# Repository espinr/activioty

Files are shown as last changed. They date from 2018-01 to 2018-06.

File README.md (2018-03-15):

# Activ-IoTy Timekeeping

> A scalable open platform for sports timekeeping based on standard IoT technologies

Activ-IoTy is a project, part of the **[Eclipse Open IoT Challenge 4.0](https://iot.eclipse.org/open-iot-challenge/)** aiming at enhancing sports timekeeping systems accurately, through IoT low-cost devices. ActivIoTy Timekeeping is an open set of tools for racing competitions (i.e., running, cycling, skating, and others) that provides easy-to-use tools for efficient timekeeping adapted to the nature of each race. ActivIoTy Timekeeping’s design is centered on rapid prototyping, open source, and standards. 

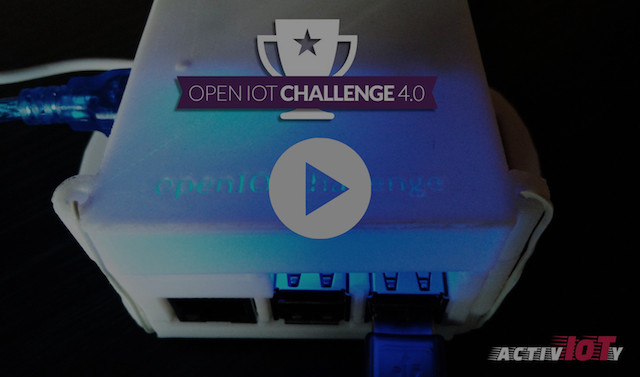
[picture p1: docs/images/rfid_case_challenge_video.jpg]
IoT Challenge 4.0 (https://youtu.be/2j3yzmwb5g8)


Read the [final report](./docs/) or [watch the video](https://youtu.be/2j3yzmwb5g8).

## Activ-IoTy at a glance

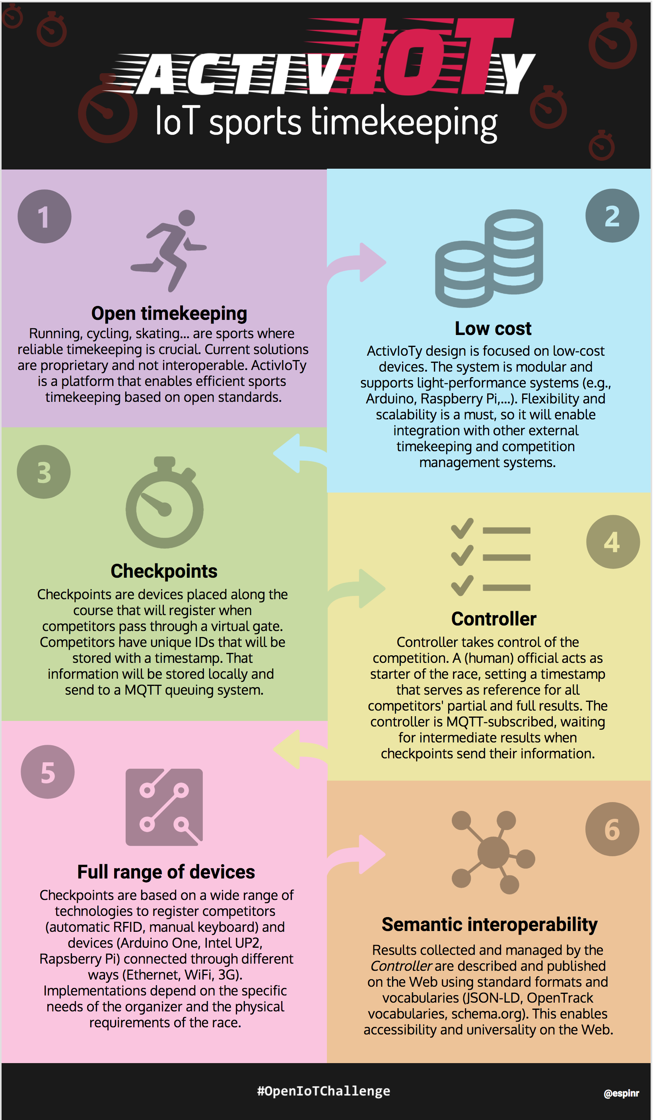
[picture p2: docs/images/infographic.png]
Activ-IoTy Infographic


* **Open timekeeping**: Running, cycling, skating… are sports where reliable timekeeping is crucial. Current solutions are proprietary and not interoperable. ActivIoTy Timekeeping is a platform that enables efficient sports timekeeping based on open standards.

   [Protocols and foundations of Activ-IoTy](./docs/protocols.md)
  
* **Low cost**: ActivIoTy Timekeeping design is focused on low-cost devices. The system is modular and supports light-performance systems (e.g., Arduino, Raspberry Pi,…). Flexibility and scalability is a must, so it will enable integration with other external timekeeping and competition management systems.
* ***Checkpoints***: Checkpoints are devices placed along the course that will register when competitors pass through a virtual gate. Competitors have unique IDs that will be stored with a timestamp. That information will be stored locally and  send to a MQTT queuing system.

   [MQTT and Workflow of Activ-IoTy](./docs/pubsub.md)
   
   [Checkpoint 1: RFID Reader + Raspberry Pi + Python](./docs/checkpoints/rfid-reader-python/)
   
   [Checkpoint 2: Bluetooth Keypad + Raspberry Pi + Python](./docs/checkpoints/bluetooth-keypad-python/)
   
   [Checkpoint 3: IR Remote + Arduino Uno](./docs/checkpoints/ir-arduino/)
   
   [Pseudo-checkpoint: Fona 3G + Arduino Lilypad](./docs/tracking/)

* ***Controller***: Controller takes control of the competition. A (human) official acts as starter of the race, setting a timestamp that serves as reference for all competitors' partial and full results. The controller is MQTT-subscribed, waiting for intermediate results when checkpoints send their information. 

   [MQTT and Workflow of Activ-IoTy](./docs/pubsub.md)
   
   [Controller](./docs/controller/)

* **Full range of devices**: *Checkpoints* are based on a wide range of technologies to register competitors (automatic RFID, manual keyboard) and devices (Arduino One, Intel UP2, Rapsberry Pi) connected through different ways (Ethernet, WiFi, 3G). Implementations depend on the specific needs of the organizer and the physical requirements of the race. 

* **Semantic interoperability**: Results collected and managed by the Controller are described and published on the Web using standard formats and vocabularies ([JSON-LD](https://json-ld.org/), [OpenTrack vocabularies](https://github.com/w3c/opentrack-cg), [schema.org](http://schema.org)). This enables accessibility and universality on the Web. 

   [Sample of results](./docs/controller/sample_results.jsonld) generated by the platform.

Check more information about the [components of Activ-IoTy](./docs/components.md)

[mainlogo]: ./docs/images/logo/activIoTy.svg "Logo of ActivIoTy Timekeeping"
[infographic]: ./docs/images/infographic.png "Components of ActivIoTy Timekeeping"

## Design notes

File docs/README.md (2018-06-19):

# Activ-IoTy Timekeeping Report

IoT Challenge 4.0 (https://youtu.be/2j3yzmwb5g8)

Watch [the video](https://youtu.be/2j3yzmwb5g8) summarizing all the work done in this project in just 3 minutes.

## 1. Description of the project

Athletics is perhaps the most popular sport in the world. It’s not only the most followed discipline during the Olympic Games, but Jogging is also extended in all countries as a base sport for kids or adult people. Fun races are also becoming popular, even among those who don’t do sports regularly. This trend is affecting positively to health and good habits of people.

More than 30 thousand running events take place in the U.S. every year, including 5k, 10k and 8K/5 mile races as well as half-marathons and marathons ([source](https://www.statista.com/topics/1743/running-and-jogging/)). It [is estimated](https://www.statista.com/statistics/190303/running-participants-in-the-us-since-2006/) that there are over 47 million of runners (doing running/jogging or trail running) in the U.S.

In EU28, figures show that running is part of the way of life of many people. For instance, the 31% of the Danish population are runners, 25% in Germany ([source](https://www.palgrave.com/gp/book/9781137446367)). Most of these runners take part in competitions. 

To make competitive running attractive among athletes, there are two important aspects to take into account: **accurate/official timekeeping**, and **publication of comparable results** for statistics and competition. We can achieve this with the complex and reliable systems of the competition organizers but this implies high costs. Also, these timing systems are not available in some developing countries.

Just as an example, in the following image of the Kenyan Cross Country Championships this year. There you can see how the *fastest* athletes in the world are selected to run in the World Championships, for instance. It shows an ordered queue of athletes, just after crossing the finish line. Two officials take notes on cardboard tables. These lists of results are published but, they won't be interoperable at all.

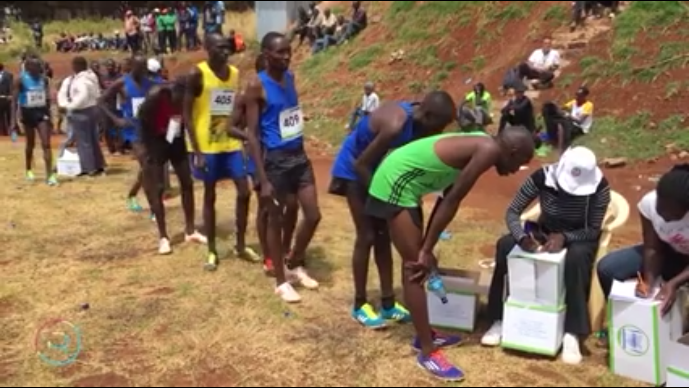
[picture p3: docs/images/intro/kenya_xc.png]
National Cross Country Championship in Kenya

Winners of the Kenyan Cross Country Championship 2018

### The solution

Activ-IoTy Timekeeping is a system that the concepts of rapid prototyping and Internet of Things to develop a modular low-cost solution for timekeeping and competition management. This system is based on standard technologies that enable **plug and play different devices** and share information with external servers to process the results, records, etc.

The following diagram shows the main components of Activ-IoTy: **Checkpoints** and **Controller(s)**.

1. *Checkpoints* registers both competitor's ID and timestamp. These components are the MQTT *publishers*.
2. *Controller*(s) collects the information sent by the *Checkpoints* and processes the information. So, these are the MQTT *subscribers*.
3. Other third-party *subscribers* may perform other activities (i.e., visualizations, integration with third-party services, etc.)  

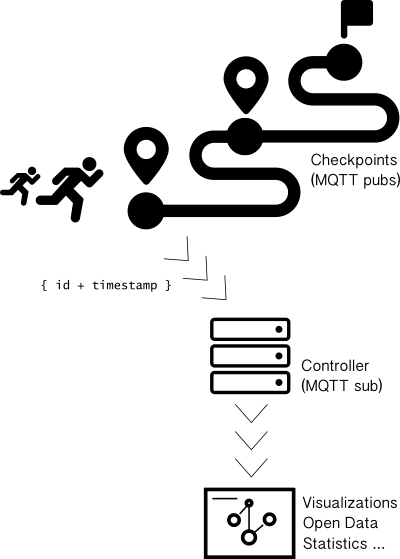
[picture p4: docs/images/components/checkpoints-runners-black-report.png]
Components of Activ-IoTy


### 1.1. *Checkpoints* 

Those components perform the timekeeping activities. They are 'virtual gates' where competitors check-in to complete the full itinerary of the race. The objective of a *checkpoint* is to inform the system which competitor arrives at that specific location, *timestamping* that check-in. Checkpoints are multimodal and fully configurable. They can be designed and implemented with different IoT components to satisfy the requirements of the race and the organizers.

This pilot includes several *checkpoints* with different devices, platforms, and configurations. This serves to test a wide range of racing scenarios.

#### 1.1.1. Checkpoint 1: RFID Reader + Raspberry Pi + Python

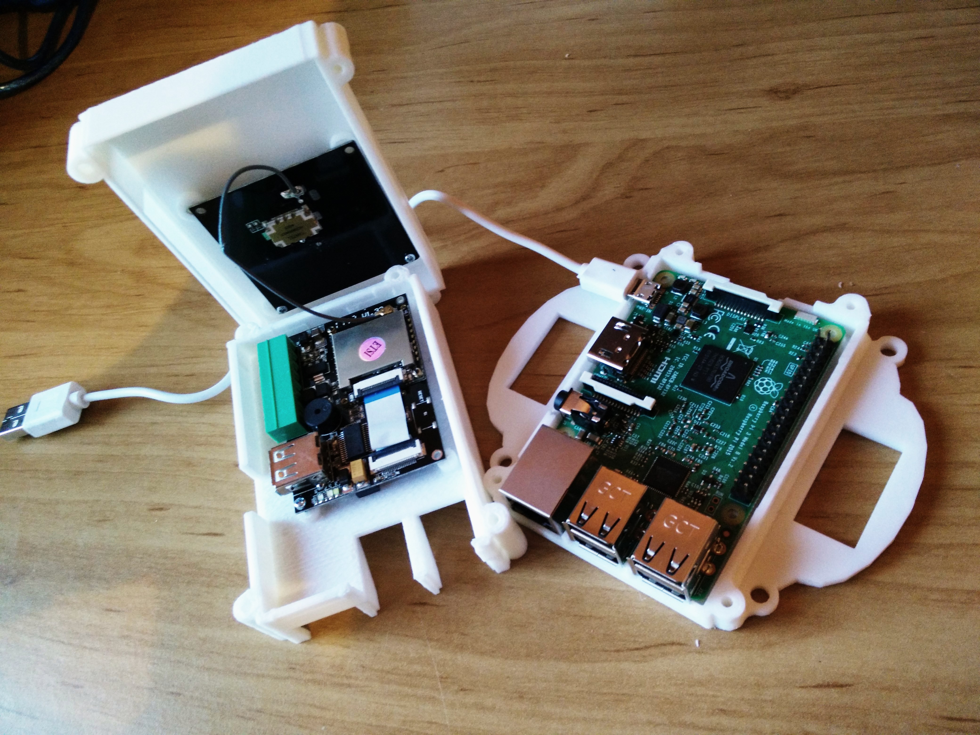
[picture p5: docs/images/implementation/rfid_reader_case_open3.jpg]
Checkpoint 1


This *Checkpoint* is based on a **IND903 UHF RFID Reader**, connected to a **Raspberry Pi** (or a **Intel Up Squared**). The reader controller, as well as the checkpoint are coded in Python. The MQTT Client is implemented using the **Paho** Python module.  

It is important to understand that each competitor taking part in a competition is identified by two unique IDs: 

1. the bib number: alphanumeric string that follows the organizers standards (it could be an alias, surname or bib number). In this case, an unsigned integer; and

2. an EPC (Electronic Product Code) corresponding to the RFID tag attached to their bib number. This tag follows the EPC C1G2 (Class 1 Generation 2) standard.

Check all the details and code in [Github page of this component](./checkpoints/rfid-reader-python).

The cost magnitude of this checkpoint depends on the antenna. The cost of the implementation of this pilot was around $150 (including RFID reader, sample tags, (5-6m reading range) antenna plus Rasberry Pi).

#### 1.1.2. Checkpoint 2: Bluetooth Keypad + Raspberry Pi + Python

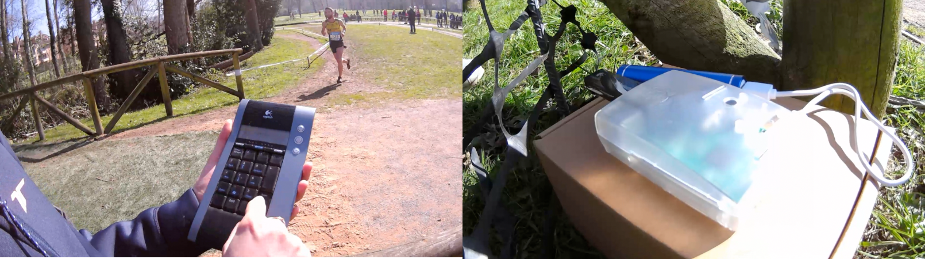
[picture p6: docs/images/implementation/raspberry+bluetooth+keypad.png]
Checkpoint 2


This is a cheap option of checkpoint implementation. 

Athletics events are usually controlled by officials with different roles such as: judges, timekeepers and starters. Other competitions must rely on officials with other roles, even volunteers or marshals. This checkpoint enables officials and volunteers to register athletes at checkpoints using a simple physical keypad to type athlete's bib numbers. 

Since all athletes must wear a visible bib identifier, this implementation is compatible with the existing rules of official competitions. Keypad may be substituted by a complete keyboard. Of course, the keypad could be a capacitive screen (i.e., tablet, smartphone, etc.) but it is probed that data input operators are more efficient with physical typing devices. Also they may be robust, even waterproof. 

Check all the details and code in [Github page of this component](./checkpoints/bluetooth-keypad-python).

The cost of this checkpoint is below $50.

#### 1.1.3. Checkpoint 3: IR Remote + Arduino Uno

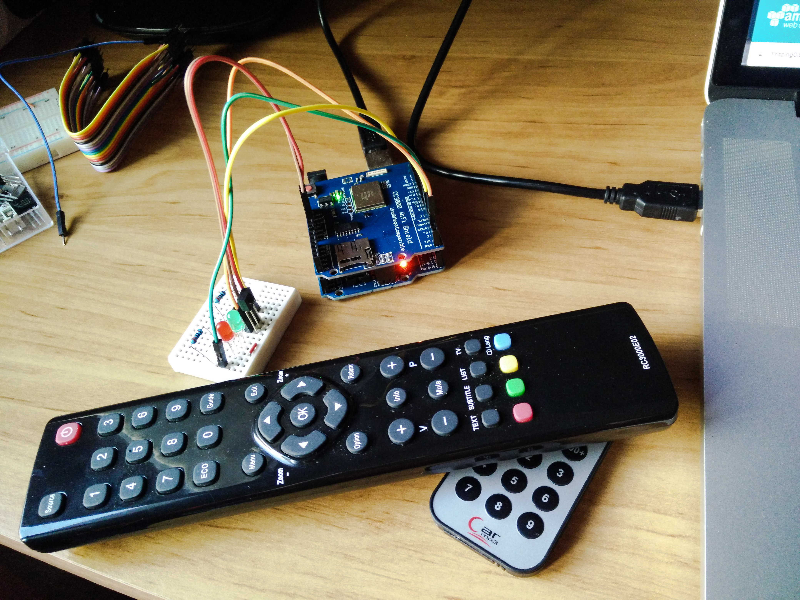
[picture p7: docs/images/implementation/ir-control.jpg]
IR Remote Control Checkpoint


Having in mind a less optimistic scenario –low budget, few resources–, I've implemented another checkpoint using a different solution. This option would cost less than $50 and it's really easy to use. It can be developed with a components from a basic Arduino-like kit. 

A system based on Infrared (IR) remote control, is not very reliable for our purpose since there must be a direct visual line between transmitter and receiver –likely TV remote controls. **More than a real solution, this is a proof of concept**.

Check all the details and code in [Github page of this component](./checkpoints/ir-arduino).

#### 1.1.4. MQTT publication

*Checkpoints* send an MQTT message once an athlete arrives. It is of the `{checkpoint-ID}/checkpoint` topic:

```
{
    "checkpoint" : { 
        "id" : "…",             // Required
        "geo" : { "lat" : "…", "lng" : "…" }    // Optional
    },
    "bibId" : "…",              // Either 'bib' or 'epc' are required
    "epc"   : "…",
    "timestamp"  : 0000000,     // (NTP) UNIX time Required
}
```

For check-in messages, it is required the checkpoint identifier (some information may be added, such as coordinates in case the checkpoint is on the move), the unique identifier of the competitor (we can have several, such as bib number and RFID tag), and the timestamp of the check-in. 

Check more information about the [PubSub design in the project](./pubsub.md).

#### 1.1.5. Scalability and further options

Trying to expand the features and ecosystem of the platform, a mobile checkpoint was created with a Fona 3G module and an Arduino Lilypad.

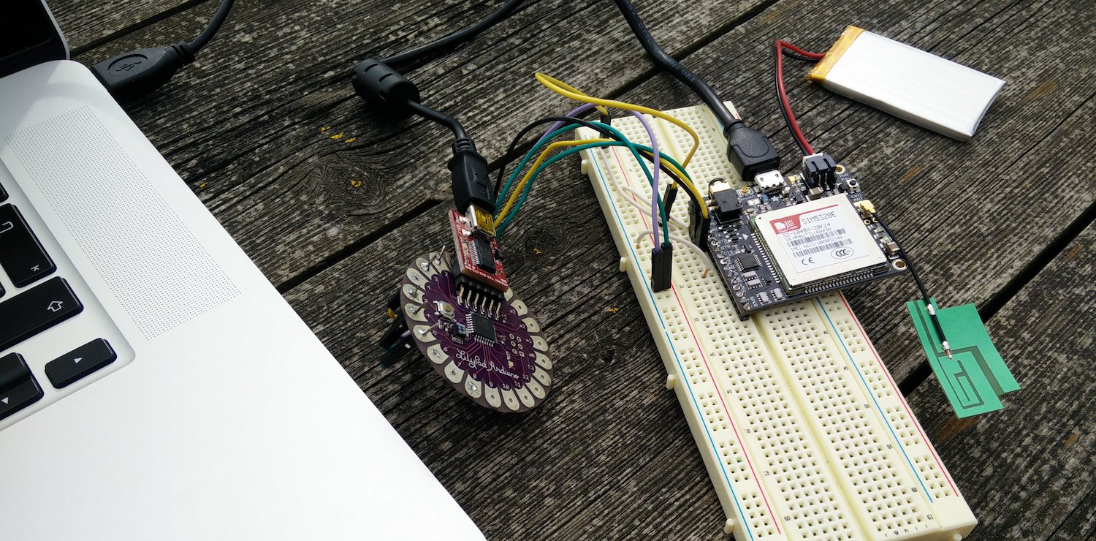
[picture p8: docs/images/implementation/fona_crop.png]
Pseudo-checkpoint


Check [more information about this checkpoint on the move](./tracking).

### 1.2. Controller(s)

A *Controller* is basically a **responsive Web application** that enables competition management, including the processing of *check-ins* performed on checkpoints along the race course. There may be several controllers for different purposes, implementing different features. The controller of this pilot enables a complete management of the competition, from the registration and management of athletes, checkpoints, race, start list and visualizing the competition in real time.

Activ-IoTy Controller screenshot (http://www.youtube.com/watch?v=nTlSV7WbGoE)
Check the [full video of a real example (at high speed) on YouTube](http://www.youtube.com/watch?v=nTlSV7WbGoE).

Read more information [about the *Controller*](./controller) and its implementation. In case you **want to [test it](http://activioty.ddns.net)**, drop me an email and I'll send you the *admin* credentials. You could sign up the app, but with the role of *athlete*, so you won't be able to create and manage races (only *admin*s can do it).

Some other components such as the **MQTT Broker** are described in [a more detailed document about components](./components.md) of the project.

> The strongest point of Activ-Ioty Timekeeping is scalability thanks to its design based on device independence and open standards.

The strongest point of Activ-Ioty Timekeeping is device independence so any kind of devices may be used to implement *checkpoints*. Likely *checkpoints*, *controllers* may be designed to manage the information to cover any competition requirement (e.g., relay races, multi-lap courses, time-trial races, and others). 

## 1.3. Technology and Standards

The cornerstone of Activ-IoTy Timekeeping is the implementation based on open standards. Since the platform is designed to allow different and heterogeneous devices and implementations, standard technologies are crucial for scalability, enhancement of the system, and also to preserve the integrity of data. 

Design and implementation were focused on the use of standard technologies, open source libraries and mounted on open hardware devices. **Python v3** and **Embed C++** are the selected programming languages for the devices (*Checkpoints*); **JavaScript**, for the *Controller*.

Stack of technologies and protocols of Activ-IoTy

Obviously, everything will run on the Internet. There are various underlying protocols since Activ-IoTy Timekeeping aims to be flexible in terms of physical connectivity. *Controllers* and *Checkpoints* may be installed in locations with strong WiFi signal (city or, town center), even with access to wired Ethernet routers, but also in the middle of the forest where we would need establish cellular GSM or 3G connections. Thus, the physical layer includes: [**IEEE 802.3 (Ethernet)**](http://www.ieee802.org/3/), [**IEEE 802.11 (WiFi)**](http://www.ieee802.org/11/) and [**WCDMA/HSDPA (3G)**](https://www.gsma.com/aboutus/gsm-technology/3gwcdma) protocols. 

In this sense, most of the tests were performed on WiFi access points, but the [Mobile Checkpoint](./tracking/) used a 3G cellular connection.

On top of the Internet, the transport layer is composed mainly by [**TCP** or Transmission Control Protocol](https://en.wikipedia.org/wiki/Transmission_Control_Protocol). [**UDP** or User Datagram Protocol](https://en.wikipedia.org/wiki/User_Datagram_Protocol) is used for specific applications such as time synchronization through external [NTP (Network Time Protocol)](http://www.ntp.org/ntpfaq/NTP-s-def.htm) servers.

### 1.3.1. MQTT, key in communications

*Checkpoints*, *controllers* and the rest of the modules are based on the Pub/Sub (Publication/Subscription) paradigm. Since the distributed system needs reliability and there is a potential lack of quality of communications, the solution uses [MQTT (Message Queuing Telemetry Transport)](http://mqtt.org/) as messaging protocol. MQTT allows *Checkpoints* (publishers) to send messages to the *Controllers* (subscribers). A *broker*, up and running in a reliable environment, will be in charge of delivering those messages effectively. 

**MQTT** implements different levels of Quality of service (QoS). **Integrity of data and rapidity is key for Activ-IoTy**. Also intermediate *Checkpoints* may be weak in terms of connectivity. Thus the system will implement **QoS 1 (at least once)**. Using QoS level 1, it is guaranteed that a message will be delivered at least once to the receiver. Messages can be delivered more than once but this will be taken into account and solved by the *Controller*.

The MQTT broker is implemented and running on a reliable UP-Squared accessible through the port 1883 of activioty.ddns.net. Regarding security, this broker does not provide a secure channel. This is a clear breach in the system but was done on purpose to offer real-time demonstrations in this prototype (i.e. jury of the challenge could subscribe to the MQTT queue in order to check the real messages running on the system, [like in the example](http://www.youtube.com/watch?v=nTlSV7WbGoE)). In case of real operation, the broker would implement either user authentication and SSL-secured transmissions.

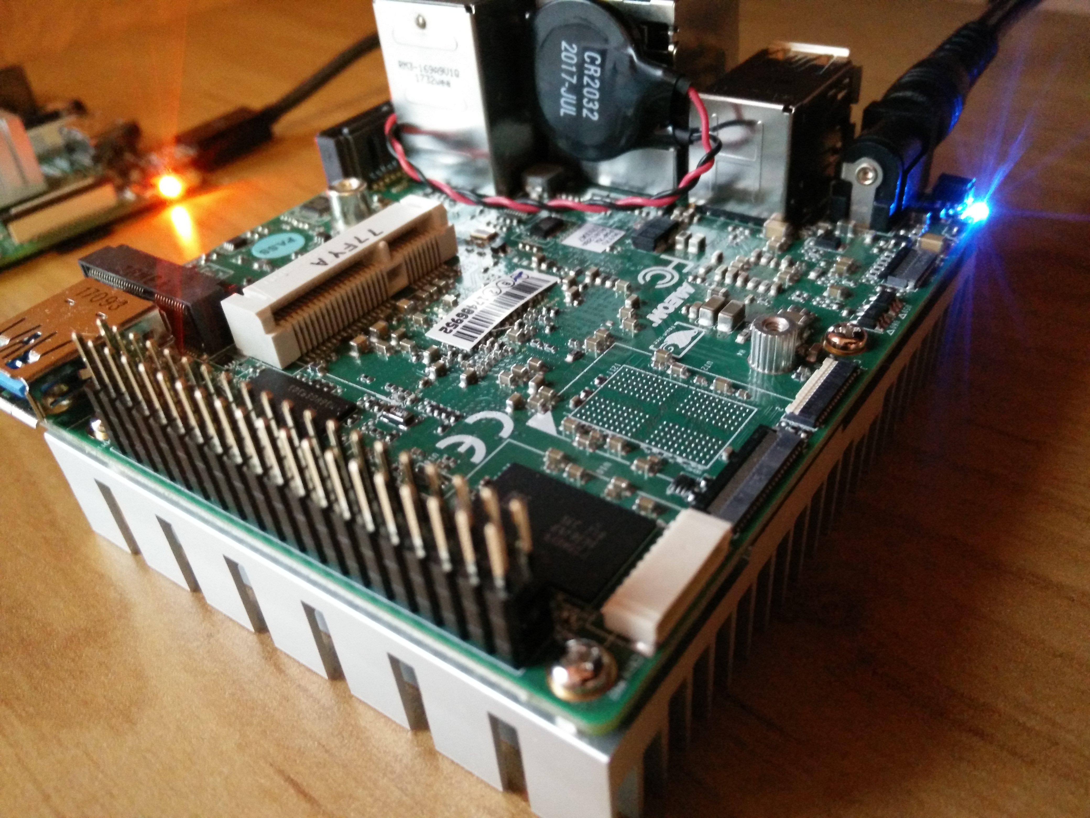
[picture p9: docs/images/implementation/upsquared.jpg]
Intel UpSquared

*UpSquared Board used for prototyping and where servers are running* 

### 1.3.2. Web Standards

The system implements some examples of visualizations and operation on the system. The *Controller* manages a MongoDB where stores all the information produced by the system, including the MQTT messages about competitors' *check-ins* at *checkpoints*. Additional Web services may be exposed on top of that database, giving access to third parties to build additional services or products. Just as an example of this, the system may offer **[HTTP (Hypertext Transfer Protocol)](https://www.w3.org/Protocols/) RESTful services** to get race results. Value of data is clear, so this may increase the usefulness of the platform, enabling innovation in further developments (e.g., integration with social networks, better visualizations, etc.). 

The final design was complemented by other specific top level standards that guarantee **interoperability among similar systems around the world**. The description of underlying entities of the database using the [**OpenTrack vocabularies**](https://w3c.github.io/opentrack-cg/), an initiative to model the domain of Athletics in a standard way. Through this **[Schema.org](http://schema.org)** based vocabulary (and taxonomies), the system describes athletes, clubs, competitions and results in a semantic way. Check the [results generated after the test](./controller/sample_results.jsonld) in **JSON-LD** format.

## 2. Applicability to industry

As mentioned before, the running/jogging market is growing every year and competitions happen everywhere at any time. There are many applications and products that probe the importance of competitiveness in this sport. For instance, most of the sports tracking mobile apps (Strava, Nike+, Endomondo, etc.) include gamification based on performances and rankings. So, Activ-IoTy is part of this trend. 

It is important to say that **reliable timekeeping systems already exist**. Indeed, this is problem solved since years ago. We are used to seeing real-time results while we watch Athletics at the Olympic Games on TV. In this case, a few big companies provide timing services to Athletics Federations to cover these competitions. Those costs are not affordable for the majority of race organizers. Another problem is the lack of open standards in those solutions, so most of them are proprietary and closed.

> Activ-IoTy Timekeeping brings innovation, new business opportunities and social benefits

Because of this, Activ-IoTy takes advantage of this *running bubble*, enabling an open platform to enrich sports. As part of the *open* concept (i.e., open source, open hardware, open data, open standards), **Activ-IoTy enables SMEs to develop new business opportunities, offering timekeeping services, including new devices and mechanisms, enhancing the final products, fostering innovation**. 

As shown in the tests, this pilot is fully functional, but not very robust –only basic features covered, and lack of testing in depth. It could become a robust platform where build services on top of it (i.e., consultancy services, specific applications, new check-in methods, integration with third-party services, etc.). Apart from the platform, there is a clear value of the data produced. Information managed by Activ-IoT could be also part of the [open data](https://en.wikipedia.org/wiki/Open_data) ecosystem, so this brings innovation, new business opportunities, and benefits for the community.

As a next step, apart from evolving the hardware of the platform, the *controller* should implement APIs to communicate with the current commercial sports systems. Integration with other platforms is key to a quick success of the platform.  

## 3. Lessons learned

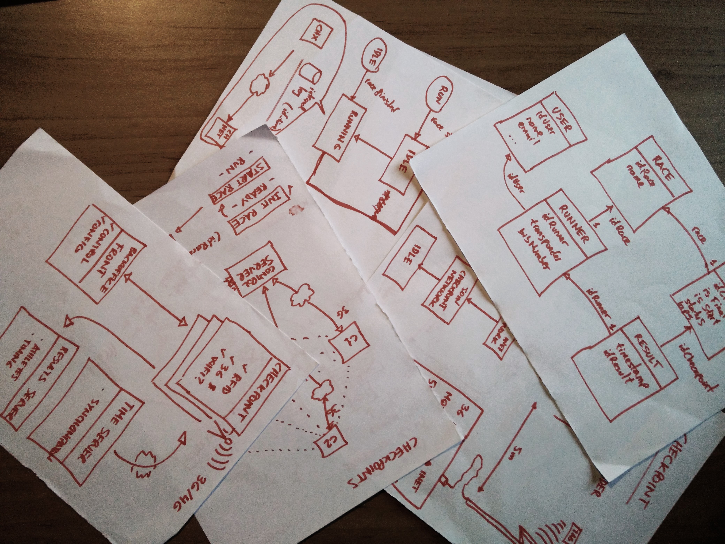
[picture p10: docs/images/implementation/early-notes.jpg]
Early notes


1. From software development to hardware prototyping. Back in December, I oriented the design phase as a software project –I have some experience in this field. When I started prototyping the checkpoints I found many issues that drove me crazy. I expected some parts to be easier, from the basic configuration of a device (e.g., installing the right BIOS, operating system, and drivers for the Intel UpSquared took me a few hours before it worked perfectly), to understanding why some implementations didn't work as expected (e.g., feeding the RFID reader with lower amperage than recommended). So, for this kind of projects, one **have to take into account more variables than a simple project of software development**.

2. *Community is key to the growth of IoT*. Developing new IoT solutions is a piece of cake. The Web is full of IoT enthusiasts aiming to help. I faced many issues during the implementation phase that were solved in minutes thanks to forums and blog posts on the Web. So, give attribution and share as well!! Eating my own dog food, code and documentation are available in the [Activ-IoTy Github Repository](https://github.com/espinr/activioty).  

3. Debugging is so hard… Most of the developments I've made for this project were based on existing libraries. Almost all worked properly at the first try, but not all. In case of low-level programming languages, such as some Arduino sketches, debugging was difficult in some parts. The lesson here is… be patient:-) 

4. **Python for arrays and bytes management**. Other software I used, such as the RDID-reader code, was created from scratch. Although I had no experience with it, I chose Python for its expected support of arrays and hexadecimal bytes required for the low-level communications protocol. It was a good experience. It's an intuitive programming language, with infinite modules to solve any challenge you face. The code may be run on some of the devices I had for the pilot (i.e., UpSquared and Raspberry Pi). 

5. **Beauty !== functional**. I bought an RFID Reader that has [worked right from the first try](https://www.youtube.com/edit?o=U&video_id=kmptDorc3zw). I used an 8dBi ceramic antenna which was enough to read tags properly in a 5-meter range. I decided to pack everything to make it portable and nice, so I designed and printed a case for a Raspberry Pi, the reader and the antenna. Making it from the scratch would be difficult, but I used an existing 3D model for a Raspberry Case on [TikerCad](https://www.tinkercad.com) to [create it](./checkpoints/rfid-reader-python/3D_model_RFID Reader + Antenna + RPi.stl).

Plastic shouldn't shield too much the readings so I designed the protective case with the antenna on top of the rest of the components.

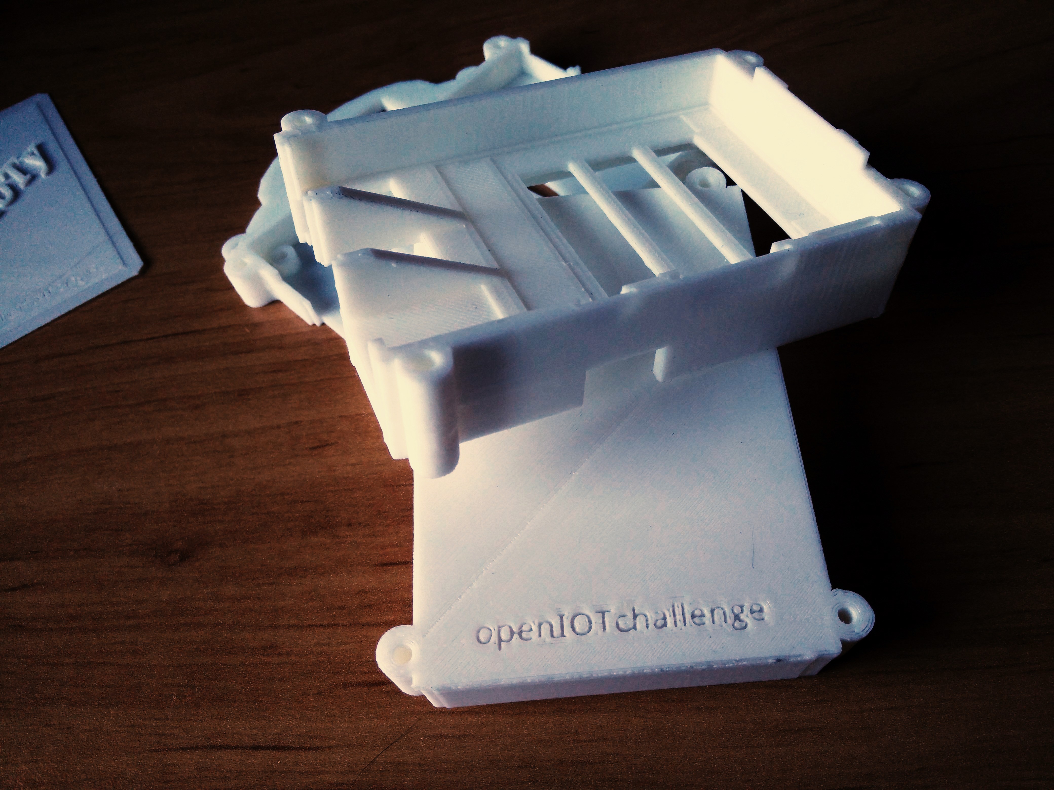
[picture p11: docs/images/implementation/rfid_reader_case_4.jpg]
3D Printed Case for the RFID Reader


I was proud of the *professional* result… Until I tested it :-) All devices worked properly, but RFID reading range decreased to a few inches. It was used to do some tests in the field (as seen in the video), but that time, the system missed around the 75% of the tags. 

I learned that both antenna and RFID tag positioning is crucial for this. Experts use the acronym SOAP to refer the four main aspects of tag positioning: Size, Orientation, Angle, and Placement. So, the recommendation is **test it (again and again)**, debugging the Receive Signal Strength Indication (RSSI) when a tag was read. 

6. **Mosquitto and Paho are cool**. I had never worked with queues. I chose MQTT and it was a really good idea. Those MQTT implementations are really stable, lightweight and easy to configure and use. 

7. **Haste makes waste**. Please, forgive me for the ugly name I chose for this project. It was a real improvisation. I sent [the proposal](https://www.youtube.com/edit?o=U&video_id=w4vCGbUDfnA) as soon as I heard of the Challenge, but this was the last day, after work (just finished the [Open Source for Industry 4.0 Webinar](https://www.meetup.com/Virtual-IoT/events/244900672/?_cookie-check=KQXWyGDLIXrJIslG)). So I improvised and submitted a vague idea I had in mind without caring too much. Now I regret it :-) 

**It was hard but I enjoyed a lot**. Nothing more to say :-) I think this was my first step in the IoT world. At least, I'll keep playing with Activ-IoTy Timekeeping. Yes, I know, In case I start some business around it, I'll change the name.

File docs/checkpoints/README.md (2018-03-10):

# Checkpoints

*Checkpoints* are those components of Activ-IoTy that performs timekeeping activities. They are 'virtual gates' where competitors check-in to complete the full itinerary of the race.

The objective of a *checkpoint* is to register what competitor is at that location and the time when they checked in.

Checkpoints are fully configurable and can be made of different IoT components to satisfy the requirements of the race.

For this pilot, I developed several *checkpoints* with different devices and platforms to simulate a wide range of racing scenarios.

* [Checkpoint 1: RFID Reader + Raspberry Pi + Python](./rfid-reader-python/)
* [Checkpoint 2: Bluetooth Keypad + Raspberry Pi + Python](./bluetooth-keypad-python)
* [Checkpoint 3: IR Remote + Arduino Uno](./ir-arduino/)
* [Pseudo-checkpoint (on the move): Fona 3G + Arduino Lilypad](../tracking)

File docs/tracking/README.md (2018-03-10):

# Competitors Tracking (Checkpoint on the move)

I’m exploring new ways to enrich the user experience of the platform, also new features to be included. The system is based on fixed checkpoints that informs organisers and the public about the status of the competition. In between of these points there is no information. The general public standing at the finish line of a competition is interested in having a constant feedback. So the system should offer information in real time about certain competitors —for instance, the first male and female in the competition.

Tracking the position of an athlete is really simple nowadays. Indeed, you can do it with mobile apps such as Strava. Carrying the smartphone is not a solution in this case, due to competitors try to avoid unnecessary overweights. Also, in case of runners that want to use this solution, in rainy days and on muddy trail courses is not a good idea. Also in ultra-distance races is not feasible due to battery lifetime.

The solution I propose is to create an active transponder that broadcast real-time notifications with the GPS location of the competitor on a GPRS connection. The aim of this component is informing in real time about the status of the race. It will be attached (e.g., sewed to a vest) to the official or volunteer that leads the race (on car, or bike).

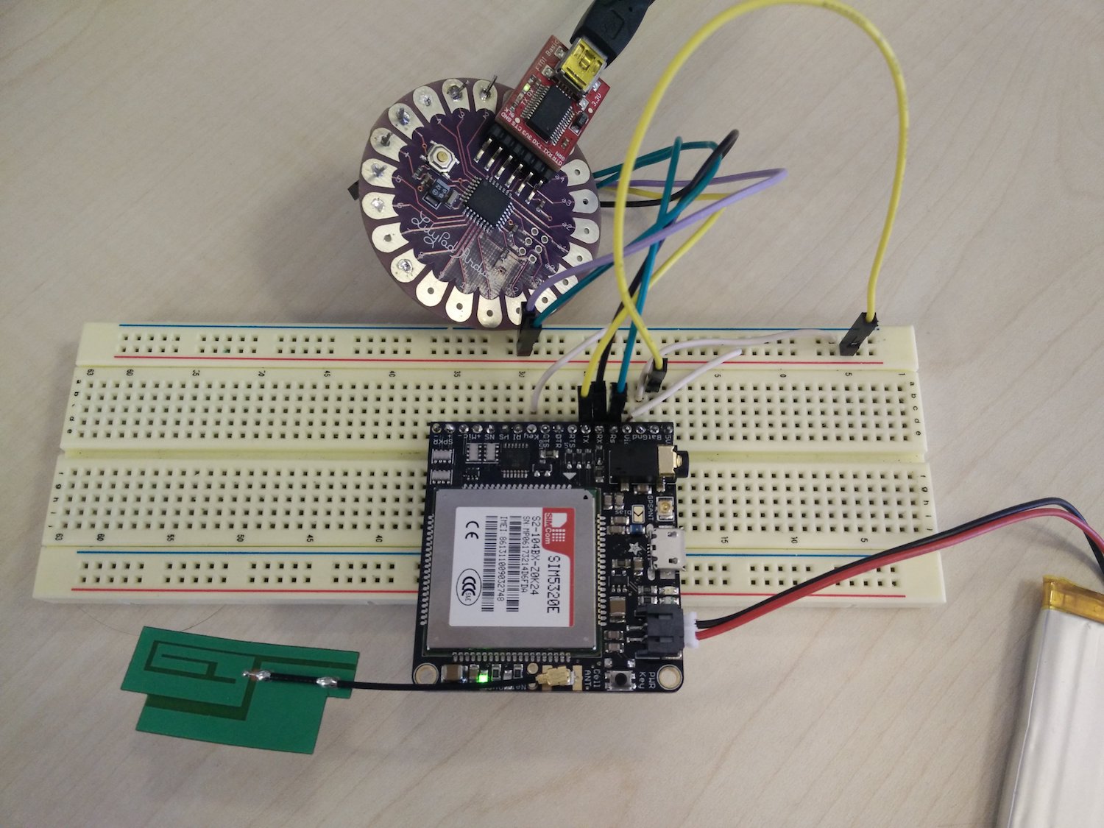
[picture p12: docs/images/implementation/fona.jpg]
Fona 3G and Arduino Lilypad


For this, I chose the [Adafruit FONA 3G Cellular Module](https://learn.adafruit.com/adafruit-fona-3g-cellular-gps-breakout/overview). The European Version of this module provides WCDMA + HSDPA support, with GSM backwards-compatibility, and a built-in GPS module for geolocation. It was controlled by a lightweight [Arduino Lilypad](https://www.arduino.cc/en/Main/ArduinoBoardLilyPad/) board, and powered by a 3.7v LiPo Battery. 

Assembly is really easy with [this Adafruit tutorial](https://learn.adafruit.com/adafruit-fona-3g-cellular-gps-breakout/assembly). This tutorial also offers a [library and examples for Arduino](https://github.com/adafruit/Adafruit_FONA). The implementation for my Lilypad was easy to adapt, just [power connections and configuration of RX, TX and RTSin (flow control)](https://learn.adafruit.com/adafruit-fona-3g-cellular-gps-breakout/arduino-wiring). If you use another Arduino model, and other pin configuration, you'll have to check its interrupt pins that are required for TX/RX.     

I've experienced problems with the code, specially with the responses to the FONA3G commands. After introducing several delays in the execution of the sketch, it runs the basic tasks we need:

1. Connect to the module and detect the version (European Version);
2. Identify the SIM IMEI;
3. Detect and connect the network;
4. Configure (APN, username and password) and establish a GPRS connection (for a Vodafone Spain SIM card);
5. Connect and fix the GPS;
6. Read the GPS location and submit coordinates to a web server;
7. (Repeat from 5)

The location collected will be sent to a script that stores and processes the information. Since the purpose of this is just testing, those coordinates will be forwarded to a variable called 'First Competitor' within [Ubidots](https://ubidots.com). I chose this platform because it provides an easy way to represent lat/log tracking of devices.      

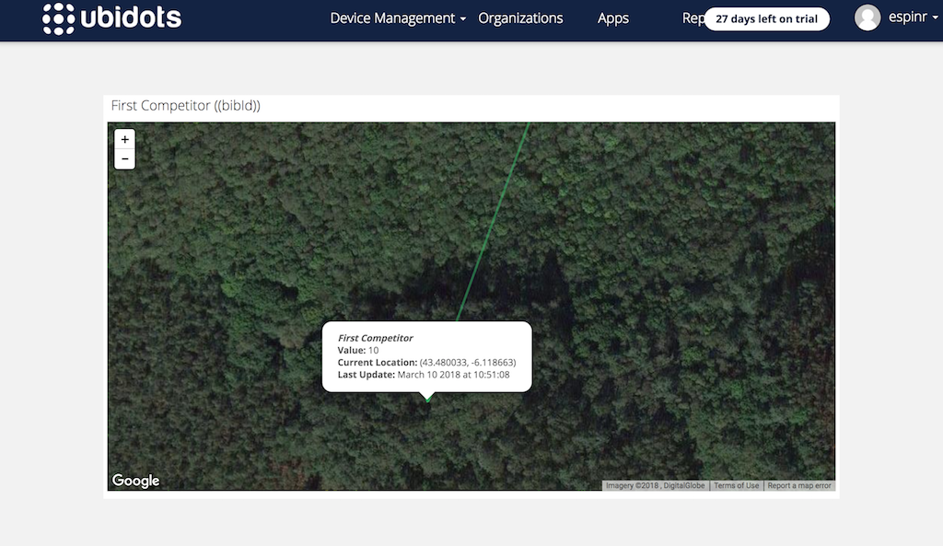
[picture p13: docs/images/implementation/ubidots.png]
Screenshot of the tracking


This is the main code of the sketch I used (trimmed for better legibility):

```
#include "Adafruit_FONA.h"

#define FONA_RX 2
#define FONA_TX 3
#define FONA_RST 5

#include <SoftwareSerial.h>
SoftwareSerial fonaSS = SoftwareSerial(FONA_TX, FONA_RX);
SoftwareSerial *fonaSerial = &fonaSS;
Adafruit_FONA_3G fona = Adafruit_FONA_3G(FONA_RST);

void setup() {
  while (!Serial);
  Serial.begin(115200);
  Serial.println(F("Initializing FONA 3G..."));

  fonaSerial->begin(4800);
  if (! fona.begin(*fonaSerial)) {
    Serial.println(F("Couldn't find FONA"));
    while (1);
  }
  type = fona.type();
  Serial.println(F("FONA is OK"));

  // Print module IMEI number.
  char imei[16] = {0};
  uint8_t imeiLen = fona.getIMEI(imei);
  if (imeiLen > 0) {
    Serial.print("Module IMEI: "); Serial.println(imei);
  }

  fona.setGPRSNetworkSettings(F("airtelwap.es"), F("wap@wap"), F("wap125"));
  fona.setHTTPSRedirect(true);
  printBatteryLevel();
  waitForNetworkConnection();
  delay(2000);
  printRSSI();
  delay(2000);
  turnGPRSOn();
  delay(5000);
  turnGPSOn();
  delay(5000);
  while (!isGPRSEnabled()) {
    delay(2000);  
  }
}

void turnGPRSOn() {
  Serial.println(F("Enabling GPRS..."));
  fona.enableGPRS(true);
}

void turnGPSOn() {
  Serial.println(F("Enabling GPS..."));
  fona.enableGPS(true);
}

uint16_t isGPRSEnabled() {
  uint16_t status = fona.GPRSstate();
  Serial.println(F("GPRS status:"));
  Serial.println(status);
  return status;
}

void waitForNetworkConnection() {
  // read the network/cellular status
  uint8_t n = 0;
  
  while (n!=1) {
    Serial.println(F("Checking network connection"));
    n = fona.getNetworkStatus();
    delay(500);
  }
  Serial.println(F("Registered (home)"));
}

void printBatteryLevel() {
  uint16_t vbat;
  while (! fona.getBattPercent(&vbat)) {
    Serial.println(F("Failed to read Battery"));
  } 
  Serial.print(F("Battery level = ")); Serial.print(vbat); Serial.println(F("%"));
}

void updateValues(float lat, float lng) {
  // read website URL
  uint16_t statuscode;
  int16_t length;
  
  String latitudeStr = String(lat);
  String longitudeStr = String(lng);
  String url = String("activioty.ddns.net/tracker/update?bibId=1&lat=" + latitudeStr + "&lng=" + longitudeStr);
  Serial.println(F("GET..."));
  Serial.println(url);

  Serial.println(F("****"));
  if (!fona.HTTP_GET_start(url.c_str(), &statuscode, (uint16_t *)&length)) {
    Serial.println("Failed!");
    return;
  } 
  while (length > 0) {
    while (fona.available()) {
      char c = fona.read();
      Serial.write(c);
      length--;
      if (! length) return;
    }
  }
  Serial.println(F("\n****"));
  fona.HTTP_GET_end();
}

void gpsFix() {
  // check GPS fix
  fona.GPSstatus();
}

void checkGPSLocation() {
  char gpsdata[120];
  fona.getGPS(0, gpsdata, 120);
  Serial.println(F("Reply in format: mode,fixstatus,utctime(yyyymmddHHMMSS),latitude,longitude,altitude,speed,course,fixmode,reserved1,HDOP,PDOP,VDOP,reserved2,view_satellites,used_satellites,reserved3,C/N0max,HPA,VPA"));
  Serial.println(gpsdata);
}

void loop() {
  printBatteryLevel();
  Serial.println(F("GPS Status..."));
  gpsFix();
  delay(5000);
  Serial.println(F("GPS Location..."));

  float latitude, longitude, speed_kph, heading, altitude;
  // if you ask for an altitude reading, getGPS will return false if there isn't a 3D fix
  boolean gps_success = fona.getGPS(&latitude, &longitude, &speed_kph, &heading, &altitude);
  delay(1000);
  if (gps_success) {
    Serial.print("GPS lat:");
    Serial.println(latitude, 6);
    Serial.print("GPS long:");
    Serial.println(longitude, 6);
    Serial.print("GPS speed KPH:");
    Serial.println(speed_kph);
    Serial.print("GPS heading:");
    Serial.println(heading);
    Serial.print("GPS altitude:");
    Serial.println(altitude);
    Serial.println(F("Updating values..."));
    updateValues(latitude, longitude);
  } else {
    Serial.println("Waiting for FONA GPS 3D fix...");
  }
  delay(30000);
}
```

You can check the [full code on Github](https://github.com/espinr/activioty/tree/master/arduino/FONA3G_GPS).

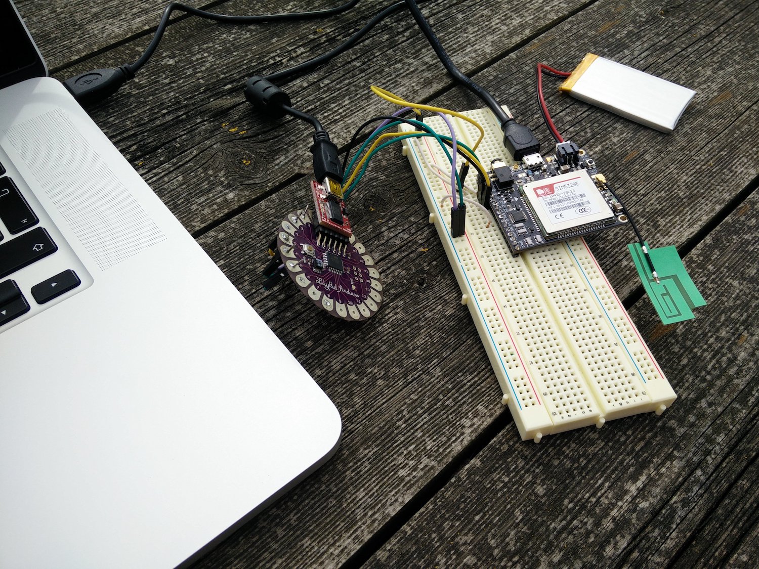
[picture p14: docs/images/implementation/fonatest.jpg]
Fona 3G and Arduino Lilypad being tested outdoors


Yes, you realized of something weird up there. The `updateValues` function makes a HTTP GET call to update values. I have some problems to use the POST method with that FONA library. Anyway, for testing purposes I created a script that posts the information from activioty.ddns.net to Ubidots.com. 

I keep experimenting with this module.

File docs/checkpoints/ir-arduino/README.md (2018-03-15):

# Checkpoint: IR Keypad on Arduino

Having in mind a less optimistic scenario –low budget, few resources–, I've implemented another checkpoint using a different solution. This option would cost less than $50 and it's really easy to use. It can be developed with a components from a basic Arduino-like kit. 

A system based on Infrared (IR) remote control, is not very reliable for our purpose since there must be a direct visual line between transmitter and receiver –likely TV remote controls. **More than a real solution, this is a proof of concept**.

IR remote control and Arduino with the checkpoint being tested

This checkpoint would help a person from the staff (volunteer, official, marshal, whoever) register the bib number of competitors at specific points along the race course. Bib numbers will be introduced through a numeric keypad. The official would **type the bib number** and **press enter**. The system will send the information (bib number + timestamp) of this `checkin` automatically.  

This module uses typical components available in most of the basic prototyping kits. So this could be implemented easily by anyone. In this case I've used components I bought years ago in my first Arduino kit:

* [**Arduino One** rev 3](https://store.arduino.cc/usa/arduino-uno-rev3)
* [**CC3000 WiFi** Shield](https://www.adafruit.com/product/1469). This could be changed for an Ethernet or 3G breakout, depending on the type of connection we will have).
* **SFH5110 Infrared Receiver**. (Other models such as the TSOP312 are also welcome) 
* Generic **remote IR control**. (I used a generic IR remote control, but you can recycle your old TV remote control).
* 2 × **LEDs**. To provide feedback when a key is pressed and a bib number is sent (or delete the current one if mistaken).
* 2 × **220 ohms resistors**.

The checkpoint would work in the same way as the rest of checkpoints:

1. **Connect** to the Internet (using the WiFi shield or any other method you need)

2. Get the **official time from a NTP server** in Unix time format. 

   In this case, the Arduino stores the offset between the internal clock and the NTP time. So it will calculate the synchronized time using the internal clock and the offset.

3. Send a MQTT `ready` message to the MQTT broker indicating the timestamp and the own ID.

4. Enter in a loop waiting for entries. 

   In this case, the Arduino enters in an infinite loop to read bib numbers [read more](#ir-receiver-and-irlib2). 
   
   The script will enter in a loop waiting for keys pressed (numbers). Once a 'number' is detected, it is included in a buffer. Two special keys will control when the bib number must be sent or deleted from the buffer. Keys in the keypad and their functions are configurable in the sketch.

## IR Receiver and IRLIB2

The transmitter in the remote control sends out a stream of pulses of infrared light (humans cannot see) when a button is pressed. A transmitter is often a light emitting diode (LED) which is built into the pointing end of the remote control handset. The infrared light pulses form a pattern unique to that button.

The Arduino sketch uses the [IRLib2](https://github.com/cyborg5/IRLib2) library to perform all the management of the IR receiver. If you are interested in in-depth information about this, you can refer to [this tutorial from Adafruit](https://learn.adafruit.com/using-an-infrared-library/hardware-needed), explaining all details about IR and how to use commercial remotes within your sketch.

I used the SFH5110 IR receiver directly connected to the Arduino's digital pin #2. You have to take into account that several digital pins are used by the CC3000 WiFi shield. 

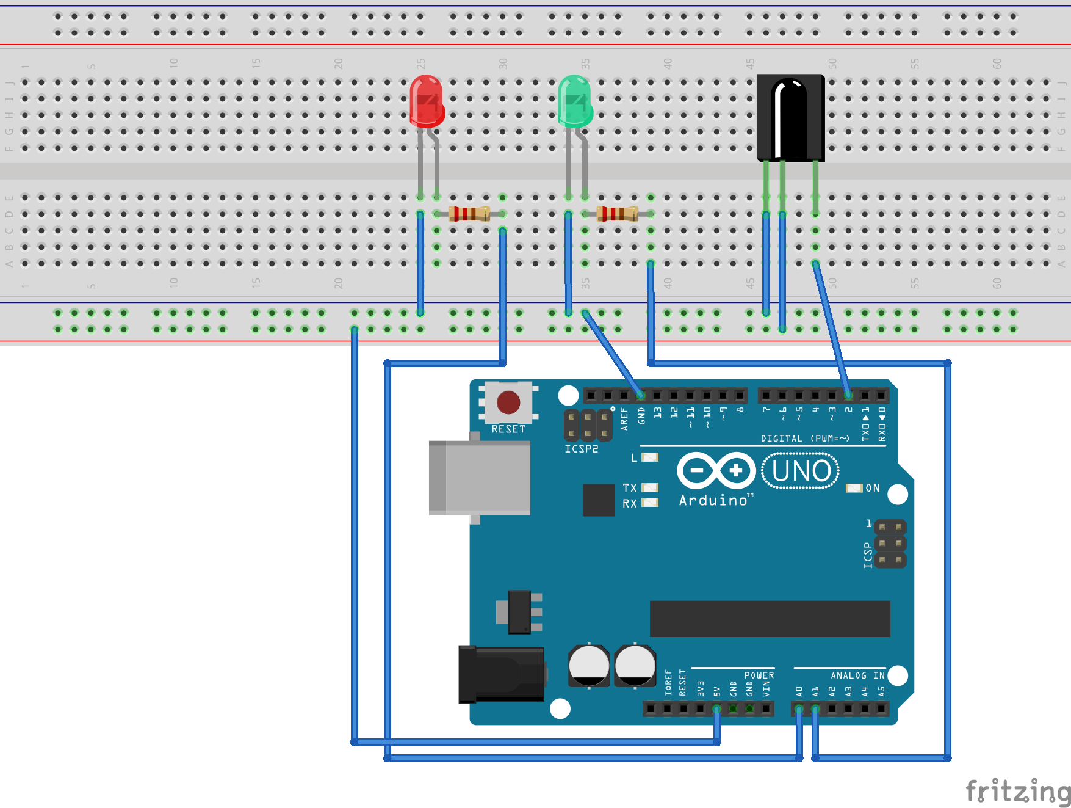
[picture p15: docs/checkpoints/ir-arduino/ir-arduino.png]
Checkpoint schematics
   

The sketch enters in a loop waiting for the receiver to read a signal (number or control key). 

The receiver will read a unique 32-bit hexadecimal data that represents the key pressed by the user. If the receiver finds something weird (e.g., several buttons pressed at the same time), returns the 0 value. The interesting thing is we can use any remote control, we can map the keys we need and run the script.

The sketch used:

```
#include "IRLibAll.h"

// LEDs connected to A0 and A1 analog pins
// the rest of the digital pins are used by CC3000  
const int LED_GREEN 	= A1;
const int LED_RED 	= A0;  

// IR receiver configuration pin
const int IR_RECEIVER = 2;

//Create a receiver object to listen on pin 2
IRrecvPCI myReceiver(IR_RECEIVER);

//Create a decoder object 
IRdecode myDecoder;   

// Key map (specific for the remote control)
const uint32_t KEY_1  = 0xFF30CF;
const uint32_t KEY_2  = 0xFF18E7;
const uint32_t KEY_3  = 0xFF7A85;
const uint32_t KEY_4  = 0xFF10EF;
const uint32_t KEY_5  = 0xFF38C7;
const uint32_t KEY_6  = 0xFF5AA5;
const uint32_t KEY_7  = 0xFF42BD;
const uint32_t KEY_8  = 0xFF4AB5;
const uint32_t KEY_9  = 0xFF52AD;
const uint32_t KEY_0  = 0xFF6897;
const uint32_t KEY_OK = 0xFFC23D;         // The green button (play)
const uint32_t KEY_CLEAR = 0xFF22DD;      // The blue 'prev' button (clear current input)

void setup() {
  Serial.begin(115200);
  delay(1000); 
  while (!Serial); 
  pinMode(LED_GREEN, OUTPUT);
  pinMode(LED_RED, OUTPUT);
  myReceiver.enableIRIn();
  Serial.println(F("[ActivIoTy Timekeeping] IR reader started"));
}

void blinkLED(int led, int delayms) {
  digitalWrite(led, HIGH);   	// turn the LED on
  delay(delayms);           		// wait for delayms
  digitalWrite(led, LOW);    	// turn the LED off
}

void loop() {  
  String bibNumber = "";   		// Bib number or name in it
  bool bibComplete = false;
  
  while (!bibComplete) {
    //Continue looping until you get a complete signal received
    if (myReceiver.getResults()) {
      myDecoder.decode();           //Decode signal received
      long value = myDecoder.value;
      switch (value) {
        case KEY_0:
          bibNumber = String(bibNumber + "0"); 
          blinkLED(LED_GREEN, 100);
          break;
        case KEY_1:
          bibNumber = String(bibNumber + "1"); 
          blinkLED(LED_GREEN, 100);
          break;
        case KEY_2:
          bibNumber = String(bibNumber + "2"); 
          blinkLED(LED_GREEN, 100);
          break;
        case KEY_3:
          bibNumber = String(bibNumber + "3"); 
          blinkLED(LED_GREEN, 100);
          break;
        case KEY_4:
          bibNumber = String(bibNumber + "4"); 
          blinkLED(LED_GREEN, 100);
          break;
        case KEY_5:
          bibNumber = String(bibNumber + "5"); 
          blinkLED(LED_GREEN, 100);
          break;
        case KEY_6:
          bibNumber = String(bibNumber + "6"); 
          blinkLED(LED_GREEN, 100);
          break;
        case KEY_7:
          bibNumber = String(bibNumber + "7"); 
          blinkLED(LED_GREEN, 100);
          break;
        case KEY_8:
          bibNumber = String(bibNumber + "8"); 
          blinkLED(LED_GREEN, 100);
          break;
        case KEY_9:
          bibNumber = String(bibNumber + "9"); 
          blinkLED(LED_GREEN, 100);
          break;
        case KEY_OK:
          bibComplete = true; 
          blinkLED(LED_GREEN, 1000);
          break;
        case KEY_CLEAR:
          bibNumber = String(""); 
          blinkLED(LED_RED, 1000);
          break;
        default:
          // do nothing, ignores and continues
          break;
      }
      //myDecoder.dumpResults(true);  //For printing results. Use false for less detail
      myReceiver.enableIRIn();        //Restart receiver
    }
  } // I have a bib identifier
  Serial.print(F("Bib number read: "));
  Serial.println(bibNumber);
}
```

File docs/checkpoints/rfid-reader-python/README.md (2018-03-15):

# *Checkpoint*: UHF RFID Reader + Raspberry Pi + Paho for Python

This Checkpoint is based on a **IND903 UHF RFID Reader**, connected to a **Raspberry Pi** (or a **Intel Up Squared**). The reader control and the checkpoint will be coded in Python. The MQTT Client is implemented using the Paho Python module. The libraries can be found [in the repository](../../../python).

It is important to understand that each competitor taking part in a competition is identified by two unique IDs: 
1. the bib number: alphanumeric string that follows the organizers standards (it could be an alias, surname or bib number). In this case, an unsigned integer; and
2. an EPC (Electronic Product Code) corresponding to the RFID tag attached to their bib number. This tag follows the EPC C1G2 (Class 1 Generation 2) standard.

## IND903 UHF RFID Reader

This *checkpoint* of ActivIoTy Timekeeping is configured to read RFID Gen 2 tags that identify competitors. In the case of running races, competitors will wear paper bib numbers with RFID tags attached to them.

The chosen solution is based on the [IND903 UHF RFID reader module](./specs/specification-IND903.pdf). The IND903 is a small reader module, operating in the 902-928MHz (US) frequency and 865.6-867.6MHz (Europe). It works over the EPC global UHF Class 1 Gen 2 (ISO 18000-6C) protocol through a USB serial Interface. The operating voltage (DC 3.5V – 5V), operating temperature (-20°C to +70°C), performance (50 tags per second during an inventory, and a label buffer of 200 labels), and low consumption (110mA at 3.5V – 18 dBm Output，25°C) makes this module appropriate for the requirements of the project.

Although the reader has a reading buffer, this pilot will use a command to perform real-time tags inventory. The default baud rate is 115200bps. Thus, at 115200 baud there is 86 microseconds between characters transmitted through the serial port. For this pilot we don't need more efficiency. 

The EPC C1G2 RFID tags will store data that identifies competitors. The memory bank of tags stores several information fields, but the most interesting for us is the 96-bit EPC (Electronic Product Code). These unique codes are the ID for the athletes in the competition.

### RFID Reading Serial Protocol 

The RFID module implements a specific USB serial protocol. It brings along specific configuration software, and a SDK to control all the complete [functions](./specs/IND903_UHF_RFID_reader_module_protocol_V2.2_en) of the reader. The SDK is designed for the Windows platform and works nicely, but ActivIoTy Timekeeping aims at running on multi-platform devices. So, I had to build my own drivers adapted to the project needs.

Commands and responses consist of byte streams. The lengths of the streams are variable, and the packets are checked by checksum (function in the [specs](./specs/IND903_UHF_RFID_reader_module_protocol_V2.2_en)).

The pilot will implement some basic commands required for the project: 
* `cmd_name_real_time_inventory`: Inventory tags in real time mode.
* `cmd_name_get_firmware_version`: Get firmware version.
* `cmd_name_set_work_antenna`: Set working antenna.

The rest of the commands may be implemented afterwards. The reader will be configured in advance (operating frequency, address, etc.) with fixed values.

#### Sample of communication protocol during the operation of the reader: 

Command 0x72 (get firmware version) sent to the reader:

```
> A0 03 01 72 EA
```
These 5 bytes correspond to:
* `A0`: head (fixed)
* `03`: Length (starting from the third byte)
* `01`: Reader’s address
* `72`: Command
* `EA`: Checksum (check all the bytes except itself)

The reader responds with this packet:
 
```
< A0 05 01 72 01 09 DE
```

That corresponds to: 
* `A0`: head (fixed)
* `05`: Length
* `01`: Reader’s address
* `72`: Command
* `01 09`: Data (`01`: major version, `09`: minor version) -> so, *v1.9*
* `DE`: Checksum

In order to set the working antenna (in our case, it is the #01) we send the following packet:

Set antenna (antenna 1):

```
> A0 04 01 74 00 E7
```
* `A0`: head (fixed)
* `04`: Length
* `01`: Reader’s address
* `74`: Command
* `00`: Data (`00` = antenna #01)
* `E7`: Checksum

The reader responds:

```
< A0 04 01 74 10 D7
```
The fifth byte is `10`: success code (command_success)

When we want to start the inventory, we send a **start inventory command** (0x89):

```
> A0 04 01 89 01 D1
```

The reader reads a tag (one or several times). In case the reader detects a tag more than once the reader only send one packet. This is the sample packet we send to the RFID reader:

```
< A0 13 01 89 04 30 00 E2 00 30 16 66 13 01 21 15 50 74 EF 45 BF
```
This packet means:
* `A0`: head (fixed)
* `13`: Length
* `01`: Reader’s address
* `89`: Command
* `04`: Antenna frequency
* `30 00`: Tag’s PC.
* `E2 00 30 16 66 13 01 21 12 50 74 EF`: **EPC**
* `45`: RSSI (The RSSI when tag is identified.)
* `BF`: Checksum

The reader may send as many packets as it reads. After those packets, the reader returns a *success reading* command (or failure):

```
> A0 0A 01 89 00 00 1D 00 00 00 01 BC
```
Bytes 10 and 11 represent the number of tags read. `00 01` one tag read.

Check the [full specs of the IND903](./specs/IND903_UHF_RFID_reader_module_protocol_V2.2_en)

### Coding in Python

The driver to control the UHF RDIF module has been written in Python (v3 because of new features to work with raw bytes). This language was chosen to be able to operate with bytes easily. It is a lightweight language with multi-platform support and it's very easy to understand. 

You can find all the Python classes and scripts in the repository. As mentioned before, not all commands are implemented but there are some classes that can be used to create packets, including checksums.  

> Do not rely too much on the scripts I created. Believe me, I did my best but it was my first experience with this language :)

The final running script will create a `Checkpoint` object that includes a `Ind903Reader` instance. The workflow will always be:

1. Set-up (set ID, address, port, etc.)
2. Check NTP time (set offset to the internal time clock)
3. Open serial USB port
4. Publish 'ready' message to the MQTT broker
5. Start inventory of tags (infinite loop: set antenna, start inventory, process reading)
5.1. Once a EPC is read, a message is published to the MQTT queue.

#### NTP client with ntplib module

ntplib module will is used to managing timestamps. The client will make a call during the setup to store the offset of the NTP time and the internal clock time.
 
ntplib is very intuitive and can be installed with PyPI `pip3 install ntplib`.

The implementation is pretty straightforward:

``` 
c = ntplib.NTPClient()
response = c.request('europe.pool.ntp.org', version=3)
```

#### Implementation of a MQTT Client with Paho for Python  

The MQTT client is implemented using the [Python Paho module](https://www.eclipse.org/paho/clients/python/). Paho for Python provides a client class with support for both MQTT v3.1 and v3.1.1 on Python 2.7 (or 3.x in this case). 

It can be installed easily via PyPI (`pip install paho-mqtt` or `pip3 install paho-mqtt` in my case).

This module provides some helper functions to make publishing one off messages to an MQTT server very straightforward. Publishing to the MQTT queue is as easy as this:

```
import paho.mqtt.publish as publish 

publish.single(“mytopic", “my message", hostname="test.mosquitto.org")
```

Since the platform will use two fixed topics (`ready` to indicate a checkpoint has joined the network and is in operation, and `checkin` to report competitor's presence or arrival at the checkpoint.

Before the device starts the inventory of competitors, the script publish a `ready` message, informing about the checkpoint station, following this structure:

```
message = {
    ‘checkpoint’ : ‘ID-CHECKPOINT’,
    ‘timestamp' : ‘NTP-UNIX-TIMESTAMP’,
}
```

Once a competitor checks in (their identifier is detected), the RFID reader publish a `checkin` message to the MQTT broker with these data:

```
message = {
    ‘checkpoint’ : 'ID-CHECKPOINT’,
    ‘timestamp' : ‘NTP-UNIX-TIMESTAMP’,
    ‘competitor’ : {
        ‘epc’ : ‘HEX-ID-RFID-TAG' 
    }
}
```

## Testing, testing

And, this is me, having fun and testing the system with real RFID tags in the kitchen:

<a href="https://youtu.be/kmptDorc3zw" target="_blank">Testing checkpoint at home</a>

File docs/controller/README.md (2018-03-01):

# The Controller

Activ-IoTy is composed of *[Checkpoints](../checkpoints/)* (devices that collects competitors' IDs, time-stamps it, and publish it), the MQTT Broker (an instance of Mosquitto Server) and the *Controller*. The *Controller* is the component that performs most of the platform's logic. 

> The Controller is a MQTT subscriber that processes the *checkins* performed on *Checkpoints*.

The Controller is basically a Web application that enables competition management, including the processing of *checkins* performed on checkpoints along the race course. There may be several controllers for different purposes, implementing different features. This controller allow us performing the following tasks: 

## Features

### Athletes Management 

Users that can sign-up into the platform and submit their profiles.

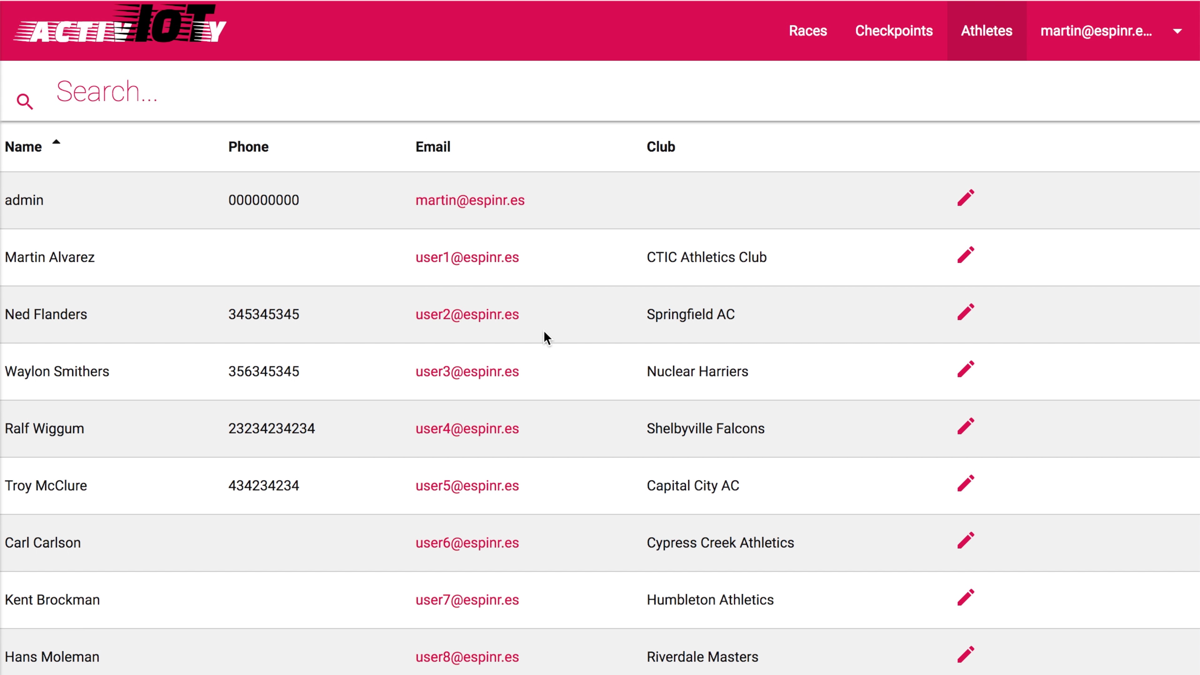
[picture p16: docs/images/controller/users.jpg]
User management


### Checkpoints Management

Creation/edition of *checkpoints*. This feature allows describing checkpoints that can be located on a map. Checkpoints are identified by their ID.

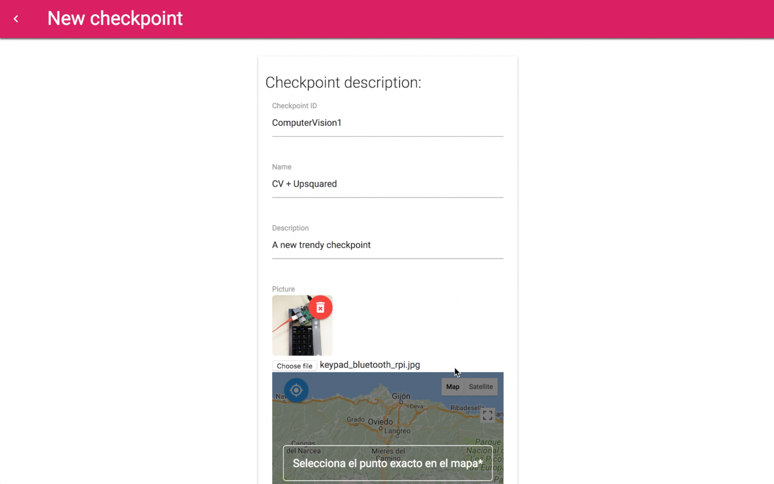
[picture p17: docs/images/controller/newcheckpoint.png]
Checkpoints management


### Race Definition

Creation/edition of races. We can describe races, including a [geo-JSON](http://geojson.org/) file with the course and the **list of *Checkpoints* ** that athletes must visit to complete the race. Checkpoints might require more than a 'checkin' to complete the race (i.e., multi-lap races). This example is limited to just 1 lap. 

Obviously, only one *Checkpoint* can be at the finish line (it has to be selected using a radio button).

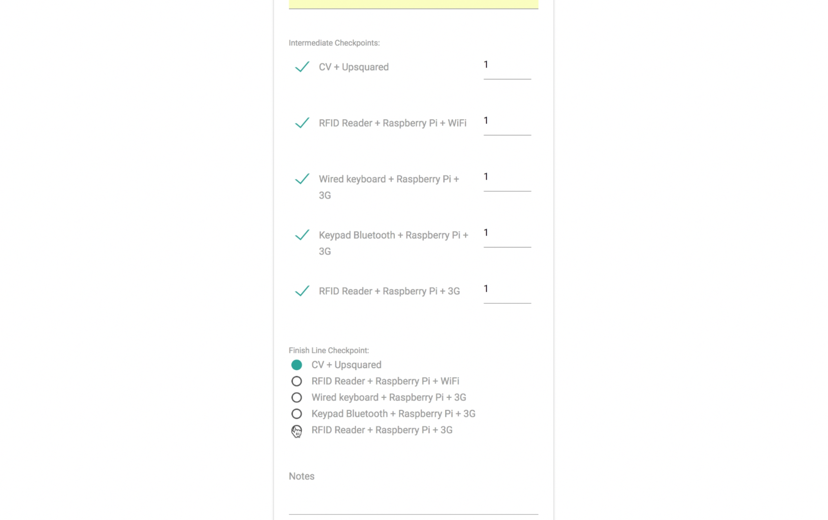
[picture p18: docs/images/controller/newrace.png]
Race management


### Start List Creation

Registered athletes may be included as competitors in specific races. There is an automatic process where selected athletes are included as competitors in a race. Competitors have assigned unique bib identifiers. 

Bib identifiers must be linked to RFID tags. For this example, I use this map of unique identifiers (included in the collection `identifiers`):

```
[
  { bibId: '001', epc: 'E2 00 51 42 05 0F 02 62 16 00 6F 40' },
  { bibId: '002', epc: '00 00 00 00 00 00 00 00 00 00 03 11' },
  { bibId: '003', epc: '00 00 00 00 00 00 00 00 00 02 49 17' },
  { bibId: '004', epc: 'E2 00 51 79 98 18 01 38 02 50 F4 9E' },
  { bibId: '005', epc: 'E2 00 51 86 06 0A 01 53 08 00 C3 10' },
  { bibId: '006', epc: 'E2 00 51 79 98 18 01 38 01 50 F9 BB' },
  { bibId: '007', epc: 'E2 00 30 16 66 13 01 21 15 50 74 EF' },
  { bibId: '008', epc: 'E2 00 41 06 21 03 00 32 10 10 AF 41' },
]
```

For this prototype, I've populated the database, loading a JSON file directly. 

The following picture shows the start list of a race. All athletes shown are the users registered in the system. The administrator may assign bib numbers to athletes directly. 

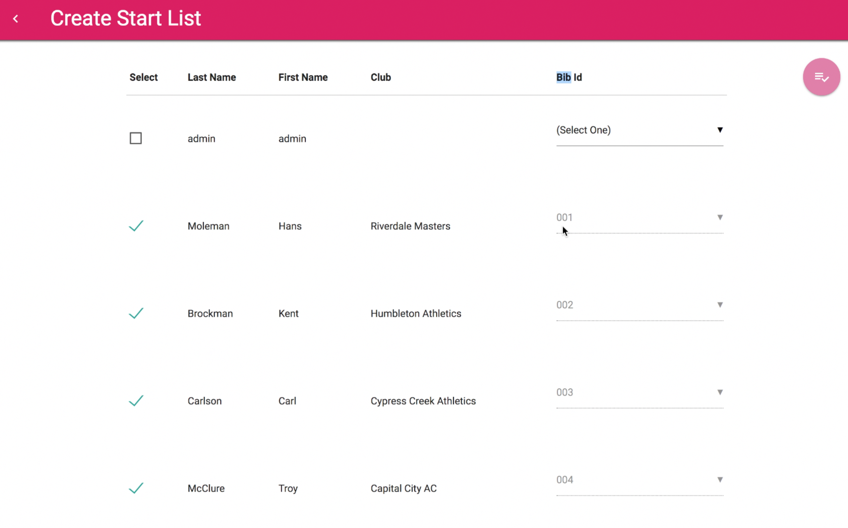
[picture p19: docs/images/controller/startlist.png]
Creation of start list


### Real-time Competition

Once a race was defined, including the *checkpoints* assigned to the course, and the start list already created, the competition is almost ready to start. The *admin* is able to open the 'live results' option. In this screen, a map with the course track and the *checkpoints* are shown. 

At the beginning, the markers representing checkpoints are in red (disabled). Now, the controller is waiting for the `ready` MQTT messages from checkpoints. As soon as a checkpoint is ready, it sends a `{checkpoint-ID}/ready` message like this (is the first message the controller received during the example):

TOPIC: `Keyboard-2/ready`

MESSAGE:

```
{
  "checkpoint" : { "id" : "Keyboard-2" },
  "timestamp"  : 1519401196
}
```

*Checkpoints* are marked in white and their *infowindow* is shown. 

At the right-hand side of the image you can see a terminal connected to the same MQTT broker, waiting for the `+/ready` messages that are processed by the controller.

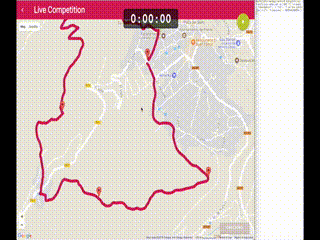
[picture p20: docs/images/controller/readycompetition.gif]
Checkpoints are getting ready in a competition


The competition starts (the *admin* presses the 'play' button'). Once the stopwatch is running the controller expects `+/checkin` messages from the checkpoints along the course. The following GIF shows the moment when competitors arrived at the first checkpoint (ID: `Keypad-1`).   

The first checkpoint is powered by a keypad so the device sends the bib number of the athlete in a message like the following example (it is the same the checkpoint sent when the first athlete did the *checkin*). In the right-hand side of the video, you can see a terminal with a Mosquitto client waiting for the same `+/checkin` messages as the controller does).

TOPIC: `Keyboard-2/checkin`

MESSAGE:

```
{
  "checkpoint" : { "id" : "Keyboard-2" },
  "bibID" : "002",
  "timestamp"  : 1519401513
}
```

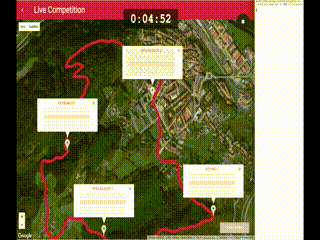
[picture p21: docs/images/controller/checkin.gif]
Athletes doing checkins at first checkpoint


The competition may be followed in real time as shown in the full video –the video was speeded up to show just the relevant events: readiness of checkpoints and *checkins* at all checkpoints. On the right hand side, there are two terminals running Mosquitto subscribers to see the real messages processed by the controller. 

#### Complete video:

Activ-IoTy Controller screenshot (http://www.youtube.com/watch?v=nTlSV7WbGoE)
Check the full video at http://www.youtube.com/watch?v=nTlSV7WbGoE

### Results in Open Format

Final results may be exported once the *admin* considers that the race is finished (other intermediate results could be exported).

This data is served in JSON-LD, following the [OpenTrack model](https://w3c.github.io/opentrack-cg/spec/model/). This vocabulary is based on [schema.org](http://schema.org) and is in process of standardisation. 

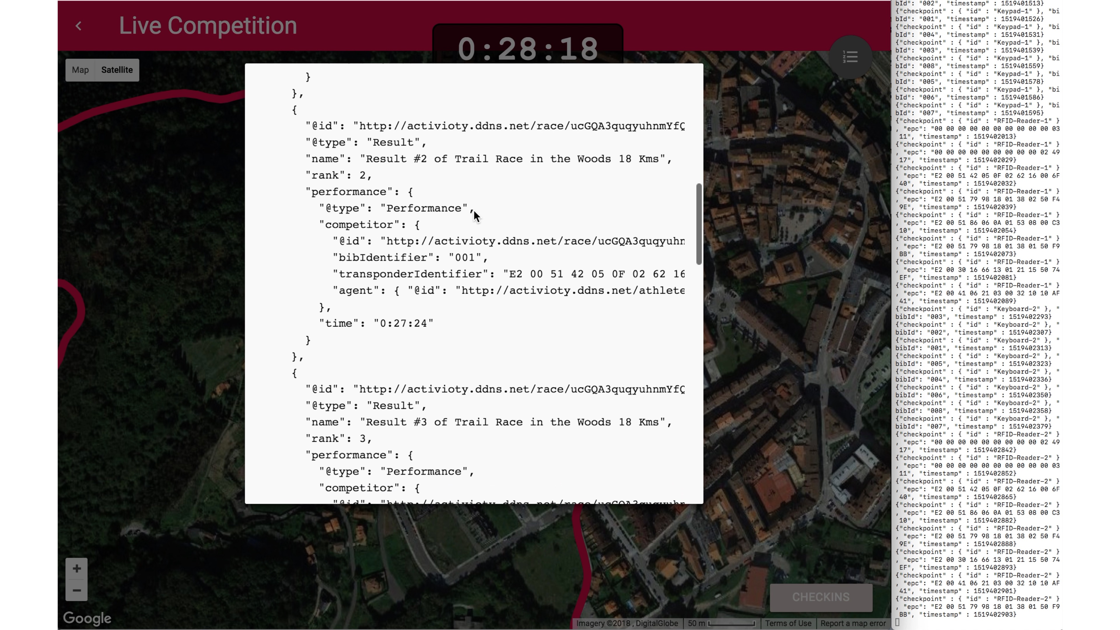
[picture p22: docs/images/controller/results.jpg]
Results export


Check the [results generated in this example](./sample_results.jsonld) –perhaps the final IRIs does not resolve, it's just an example. 

## Implementation

The *Controller* is developed in [Meteor](https://www.meteor.com), an open source platform for Web, mobile, and desktop applications build in JavaScript. The resulting mobile web application is compatible with all the latest browsers and it has been designed using the responsive web design approach, in concrete through the [Materialize CSS](http://materializecss.com/) framework.

In terms of technology, the application is built in JavaScript and is run on a [Node.js](https://nodejs.org/en/) server, and a [MongoDB](https://www.mongodb.com/) as the subjacent database system.

The application **is fully operational** and you can test it, but it is in an early development phase so it implements exactly the requirements of the pilot.

### MQTT for in Javascript

The system uses [MQTT.js](https://www.npmjs.com/package/mqtt), a client library for the MQTT protocol. It is written in JavaScript for node.js and any browser. It can be installed through NPM with just the following command:

```
npm install mqtt --save
```

Since the application must be subscribed to the MQTT queue, mqtt.js is configured in the server side of Meteor to wait for new messages from checkpoints. During the startup of the *Controller*, the a new subscription is setup (to topics `+/ready` and `+/checkin`. Also the callbacks of these events are configured.

Once a new *checkin* is detected, the *Controller* creates a new document on the `checkins` collection in the database with all the information of the received *checkin*. Also, when it detects that a checkpoint is ready, a `ready` flag in the database is updated to `true`. The concrete code is this:

```
/*
 * File at /imports/startup/server/mqtt.js
 */

import { Meteor } from 'meteor/meteor';
import mqtt from 'mqtt';
import Sntp from 'sntp';
import { Checkpoints } from '../../api/checkpoints/checkpoints.js';
import { Identifiers } from '../../api/identifiers/identifiers.js';
import { Checkins } from '../../api/checkins/checkins.js';

if (Meteor.isServer) {
  const mqttBroker = {
    url : 'mqtt://activioty.ddns.net',
    port: 1883,
  };

  const mqttClient = mqtt.connect(mqttBroker.url, mqttBroker.port);

  mqttClient.on('connect', () => {
  	const timestamp = Sntp.now();
    mqttClient.subscribe({ '+/ready': 1, '+/checkin': 1 });
    mqttClient.publish('controller/ready', `{ "checkpoint" : { "id" : "I am the controller :-)"}, "timestamp" : ${timestamp} }`);
  });

  mqttClient.on('message', Meteor.bindEnvironment((topic, message) => {
    const timestamp = Sntp.now();
    console.log(`MQTT Message received [${topic.toString()}] -> ${message.toString()}`);
    if (topic.includes('/ready')) {
      // Marks the checkpoint as ready
      try {
        const msg = JSON.parse(message.toString());
        Checkpoints.update({ identifier: msg.checkpoint.id }, { $set : { ready : true } }, (error, result) => {
          if (error) { console.log(error); }
          if (result) {
            console.log(`${result} Checkpoint ${msg.checkpoint.id} is marked as ready (${msg.timestamp})`);
          }
        });
      } catch (e) {
        console.log('I cannot process the readiness of a checkpoint, so I skip it');
      }
    } else if (topic.includes('/checkin')) {
      // Includes the athlete in the checkins database
      try {
        const msg = JSON.parse(message.toString());
        const checkpoint = Checkpoints.findOne({ identifier: msg.checkpoint.id });
        let identifier;
        if (msg.epc) {
          identifier = Identifiers.findOne({ epc: msg.epc });
        } else {
          identifier = Identifiers.findOne({ bibId: msg.bibId });
        }
        const docToInsert = {
          checkpointId: checkpoint._id,
          bibIdentifier: identifier.bibId,
          epc: identifier.epc,
          timestamp: msg.timestamp,
        };
        Checkins.insert(docToInsert, (error, result) => {
          if (error) { console.log(error); }
          if (result) {
            console.log(`Checkin of Bib Number ${identifier.bibId} at ${checkpoint.name}`);
          }
        });
      } catch (e) {
        console.log('I cannot process the checkin in a checkpoint, so I skip it');
      }
    }
  }));
}
```

The controller will process and work directly with the `checkins` collection in the database. 

#### mqtt-collection package for Meteor

Another alternative, that was tested but not used in the final solution is [mqtt-collection](https://github.com/perak/meteor-mqtt-collection), a MQTT package for Meteor that collects and stores the MQTT messages received. Messages are stored in the MongoDB directly, enabling reactive support for the client side.

This package is easy to use. The following code includes the definition of the MQTT `messages` collection and establishes the connection with the MQTT broker, indicating the topics. 

```
/*
 * File at /imports/api/messages/messages.js
 */
import { Meteor } from 'meteor/meteor';
import { Mongo } from 'meteor/mongo';

export const Messages = new Mongo.Collection('messages');

if (Meteor.isServer) {
  Messages.mqttConnect('mqtt://activioty.ddns.net:1883', ['+/ready', '+/checkin'], { insert: true }, {});
}
```

### Timing 

In order to adjust time to the common NTP servers, the system uses the [**sntp package**](https://www.npmjs.com/package/sntp). This is a SNTP v4 client (RFC4330) for Node.js. It allows the server connecting to the NTP server and returns the server time along with the roundtrip duration and clock offset. To adjust the local time to the NTP time we would need to add the returned offset to the local time. 

The main stopwatch of the application is built with [aldeed:clock](https://github.com/aldeed/meteor-reactive-clock), An accurate reactive clock package for Meteor that retains elapsed time. Usage is simple and reliable. 

This is a summary of the main declarations related to the official stopwatch of the competition:

```
/* 
 * file at: /imports/ui/components/competition/competition.js
 */ 

Template.competitionMain.onCreated(() => {
  // ...
  template.CompetitionClock = new ReactiveClock('ExerciseClock');
  template.CompetitionClock.setElapsedSeconds(0);    
  // ... 
}

Template.competitionMain.helpers({
  stopwatch() {
    const template = Template.instance();
    return template.CompetitionClock.elapsedTime({ format: '00:00:00' });
  },
  // ...
});

Template.competitionMain.events({
  'click #startCompetition-button'(event) {
    const template = Template.instance();
    template.CompetitionClock.start();
    template.startTimestamp.set(Sntp.now() / 1000);
    // ...
  },
  'click #finishCompetition-button'(event) {
    const template = Template.instance();
    template.CompetitionClock.stop();
    template.finishTimestamp = Sntp.now();
    // ...
  },
});
```

### Athlete's Checkins

If the clock is enabled (ongoing competition), the controller system waits for `checkin` messages. The application runs this code, once a new checkin is included in the database:  

```
  Tracker.autorun(() => {
  	// Gets the current Race
    template.currentRace = Races.findOne({ _id: raceId });
    if (template.currentRace && template.currentRace.checkpoints) {
      template.currentRace.checkpoints.forEach((checkpoint) => {
      	// creates a local array with checkpoints
        template.checkpoints.push(Checkpoints.findOne({ _id: checkpoint.id }));
      });
    }
    // If the clock is running 
    if (template.startTimestamp.get() && template.startTimestamp.get() > 0) {
      template.subscribe('checkins.after', template.startTimestamp.get());
      template.checkpoints.forEach((checkpoint) => {
        const checkinsForCheckpoint = Checkins.find({ checkpointId: checkpoint._id });
        if (checkinsForCheckpoint) {
          checkinsForCheckpoint.forEach((checkin) => {
            let competitor;
            if (checkin.epc) {
              competitor = Competitors.findOne({ epc: checkin.epc });
            } else {
              competitor = Competitors.findOne({ bibId: checkin.bibId });
            }
            const totalTime = checkin.timestamp - template.startTimestamp.get();
            // The rest of the logic in the application (show it on a map, store results, etc.)
            checkinAthlete(template, checkpoint, competitor, totalTime);
          });
        }
      });
    }
  });
```

This pilot illustrates how to the data can be processed and visualized. Other services and products on top of it are unlimited.

## Deployment and testing

*Activ-IoTy Controller* is deployed on a UPsquared I have at home. 

UPsquared

We have done several tests in the real World.
 
Me with a RFID tag

I'll post the URL of the controller for you to test it if you want.

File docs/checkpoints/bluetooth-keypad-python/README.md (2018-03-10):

# Checkpoint: Bluetooth Keypad on Rasperry Pi

This is a cheap option to implement an Activ-IoTy compatible checkpoint. 

Athletics events are usually controlled by officials with different roles such as: judges, timekeepers and starters. Other competitions must rely on officials with other roles, even volunteers or marshals. This solution enables officials and volunteers to register athletes at checkpoints using a simple physical keypad to type athlete's bib numbers.

Since all athletes must wear a visible bib identifier, this implementation is compatible with the existing rules of official competitions. Keypad may be substituted by a complete keyboard. Of course, the keypad could be a capacitive screen (i.e., tablet, smartphone, etc.) but it is probed that data input operators are more efficient with physical typing devices. Also they may be robust, even waterproof.  

This solution only needs a bluetooth input device connected to a Raspberry Pi, or similar.

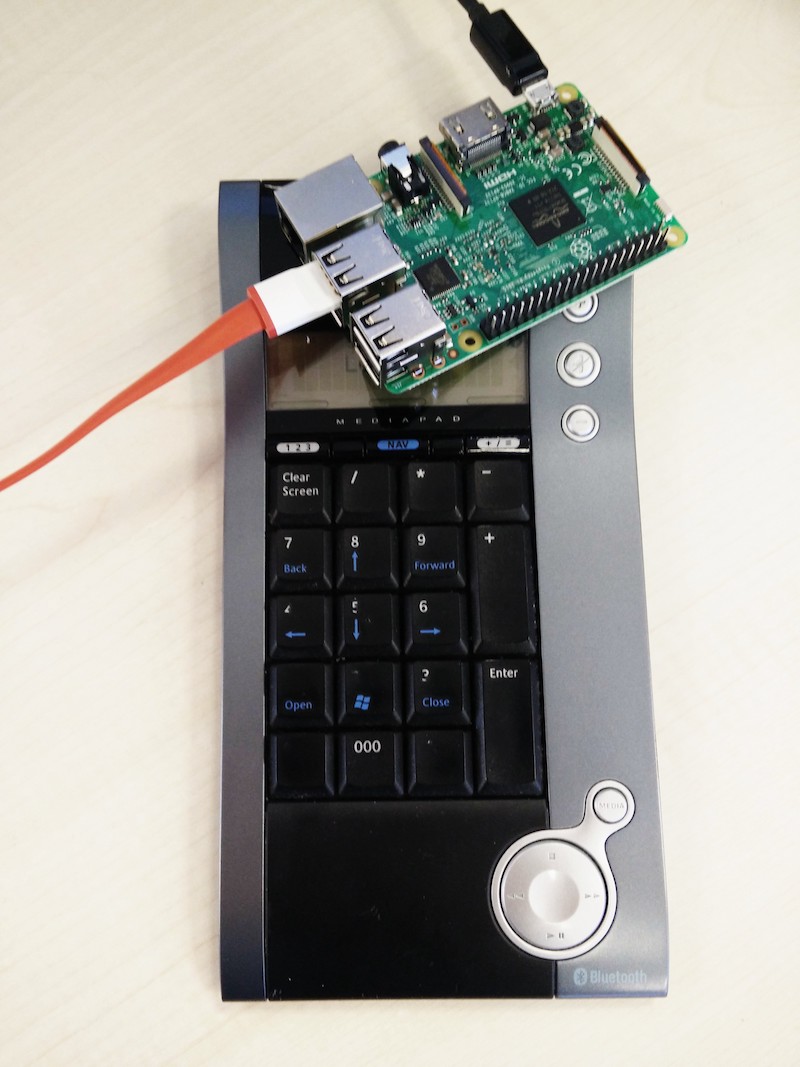
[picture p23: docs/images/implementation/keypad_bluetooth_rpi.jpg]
Bluetooth keypad and Raspberry Pi 3


The official located nearby the checkpoint **type the bib number** and **press enter** to register athletes' *checkinw*. The system will send the information (bib number + timestamp) of this `checkin` automatically.  

The implementation is based on the module I developed to implement the [Checkpoint based on a RFID Reader](../rfid-reader-python/).

Both approaches implement a generic `Reader` that performs two main tasks: `initialization` (setup of the checkpoint) and `doInventory`. 

```  
class Reader(object):
    def __init__(self):
        pass
        
    def initialize(self):
        pass
    
    def doInventory(self):
        pass     
```

They also use a common class `Checkpoint` that implements all the basic functionality of a checkpoint: 

* Get reliable timestamps from a common NTP server;
* Establish a connection with the MQTT server (once it is connected and set-up sends a `{checkpointId}/ready` message);
* Through a `Reader`, read either bib numbers or RFID EPCs that are related to each competitor (once they are read, they are sent to the MQTT queue under the topic `{checkpointId}/checkin`);
* This is executed in an infinite loop. The controller will be in charge of deal with the messages and do the business logic. 

The Checkpoint is implemented using [ntplib](https://github.com/Tipoca/ntplib) and [paho.mqtt](https://www.eclipse.org/paho/clients/python/). This is a summary of the code:

```     

# ... more imports ...

import ntplib
import paho.mqtt.publish as publish   

class Checkpoint(object):
    
    TOPIC_READY     = 'ready'
    TOPIC_CHECKIN   = 'checkin'
    
    def __init__(self, id, reader, mqttBrokerHost, mqttBrokerPort=1883):
        '''
        :param id: String with the identifier of the Checkpoint
        :param reader: Ind903Reader object (or other Reader) that will do the inventory
        :param mqttBrokerHost: String with the hostname of the MQTT broker
        :param mqttBrokerPort: (int) with the port of the MQTT broker (1883 by default)
        '''
        self.id = id
        self.reader = reader
        self.mqttBrokerHost = mqttBrokerHost
        self.mqttBrokerPort = mqttBrokerPort
        self.timestampOffset = self.getOffsetNTPTime()

    def checkinCompetitor(self, idCompetitorEPC, idCompetitorBibNumber):
        '''
        Method to be called once a competitor do a check-in. 
        This is a callback method to be send to the reader. 
        It sends a MQTT message to the broker
        :param idCompetitor: String with the ID of the competitor that the reader detected.
        '''
        competitor = {}
        if (idCompetitorEPC != None):
            competitor["epc"] = idCompetitorEPC; 
        if (idCompetitorBibNumber != None):
            competitor["bib"] = idCompetitorBibNumber;
            
        messageCheckin = { "checkpoint" : self.id , "timestamp" : self.getTimestamp(), "competitor" : competitor }
        topic = self.id + "/" + self.TOPIC_CHECKIN
        publish.single(topic, json.dumps(messageCheckin), hostname=self.mqttBrokerHost)
        print(topic + " topic to MQTT:")
        print(json.dumps(messageCheckin))
        
    def execute(self):
        messageReady = { "checkpoint" : self.id , "timestamp" : self.getTimestamp() }  
        topic = self.id + "/" + self.TOPIC_READY
        publish.single(topic, json.dumps(messageReady), hostname=self.mqttBrokerHost)
        print(topic + " topic to MQTT:")
        print(json.dumps(messageReady)) 
        self.reader.initialize()
        self.reader.doInventory(self.checkinCompetitor)

    def getOffsetNTPTime(self):
        '''
        Get timestamp from a NTP server and stores the offset with the internal clock.
        :return: (float) with the difference between the local clock and the NTP time (in seconds)
        '''
        c = ntplib.NTPClient()
        response = c.request('europe.pool.ntp.org', version=3)
        # convert from seconds since 1900 to seconds since 1970
        ntpUnixtime = response.tx_timestamp - 2208988800
        timestampOffset = time.time() - ntpUnixtime;
        return timestampOffset 

    def getTimestamp(self):
        '''
        Returns the local time plus the offset registered at the beginning.
        :return: long with the current timestamp (unix time)
        '''
        return int(time.time() + self.timestampOffset)
```

The key part of this code is the execution itself:

```
    def execute(self):
    		...
		self.reader.doInventory(self.checkinCompetitor)
```

When the checkpoint is correctly setup, the reader is asked to start the inventory of runners. Once either a bibNumber (from a keyboard input) or a EPC (from the RFID reader) is detected the `checkinCompetitor` callback is executed. This method creates the message for the MQTT receivers that will contains the information about the competitor id.   

The functionality of this specific checkpoint is implemented using the following main method: 

```
# ... imports

if __name__ == '__main__':
    reader = usb_keypad_reader.USBKeypadReader()
    checkpoint = checkpoint.Checkpoint('Keypad-1', reader, 'activioty.ddns.net')
    checkpoint.execute() 
```

Any other USB keyboard is accepted as well.

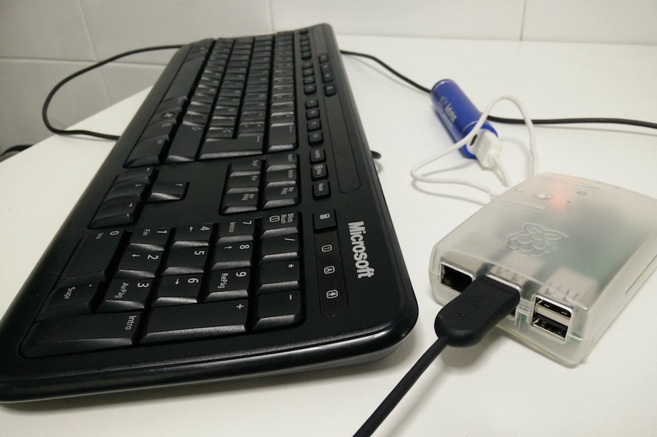
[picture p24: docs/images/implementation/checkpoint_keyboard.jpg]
Wired keyboard and Raspberry Pi 3
 

This approach may be extended to other *checkin* mechanisms such as bar-code readers or computer vision analyzers. Perhaps for the next release ;-)

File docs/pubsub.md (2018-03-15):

# ActivIoTy Timekeeping - MQTT and Workflow 

The platform is based on the pub-sub paradigm. This means that some components (*publishers* or *senders*) send messages to a central point, called *broker*, that delivers the messages to other components (*subscribers* or *receivers*) interested in receiving the information send by the *publishers*.

Just as a reminder of what the system does: 

1. *Checkpoints* registers { competitor's ID + timestamp }. So, these are the *publishers*
2. *Controller*(s) collect the information sent by *Checkpoints* and process the information. So, this is one of the *subscribers*.
3. Other *subscribers* may perform other activities (i.e., visualizations, integration with third party services, etc.)  

pubsub

## MQTT

> It's a good choice for systems where we need to share small code messages, and the network bandwidth may be limited

This mechanism is implemented using [MQTT 3.1.1](http://mqtt.org/), an OASIS standard that is widely adopted by industries and IoT solutions. MQTT is a light-weight protocol suitable for Activity, due to the flexibility requirements regarding the conditions where *Checkpoints* operates. MQTT guarantees connections with remote locations. It's a good choice for systems where we need to share small code messages, and the network bandwidth may be limited. So, it's a perfect choice for ActivIoTy Timekeeping.

MQTT ensures the data is delivered properly to *subscribers*. The *broker* is in charge of delivers messages, according to three [Quality of Service (QoS) levels](http://docs.oasis-open.org/mqtt/mqtt/v3.1.1/os/mqtt-v3.1.1-os.html#_Toc398718099): 

* **QoS 0: At most once delivery**. No response is sent by the receiver and no retry is performed by the sender. This means that the message arrives at the receiver **either once or not at all**.
* **QoS 1: At least once delivery**. This quality of service ensures that the message arrives at the receiver at least once.
* **QoS 2: Exactly once delivery**. This is the highest quality of service, for use when neither loss nor duplication of messages are acceptable.
     
Since ActivIoTy Timekeeping needs to satisfy completeness and integrity of data gathered by *Checkpoints*, the chosen QoS level is **QoS 1 (At least once delivery)**. QoS 2 would be also adequate but it increases the overhead of communications. There may be duplicates, that will be filtered by receivers without too much cost associated.

## Topics and Messages

Application messages within the MQTT queue are related to *topics*. So, both sender and receivers may work with messages organized by topics. [Topics](http://docs.oasis-open.org/mqtt/mqtt/v3.1.1/os/mqtt-v3.1.1-os.html#_Toc398718106) follow a hierarchical structure (e.g. `bedroom` to indicate all messages related to a bedroom; `bedroom/temperature` and `bedroom/humidity` for specific messages sent by sensors in the bedroom). This  that is useful for subscribers to filter and receive only the information they need. Forward slash (‘/’ U+002F) is used to separate each level within a topic tree structure.

*Checkpoints* generate two kind of application messages:

1- Readiness messages (topic `ready`). They are sent once the Checkpoint is initialized and connected to the network.   
2- Check-in messages (topic `checkin`). They are sent after the check-in of a competitor.

The definition of topics may be as complex as we want, In my case, the schema of topic names is based on the id of the checkpoint and the type of message. This is: `{checkpointID}/ready` and `{checkpointID}/checkin`.

Receivers may be subscribed to topics in a flexible way, using wildcards. For instance, `+/ready` to subscribe to all `ready` topics from all senders.

Messages will be encoded as UTF-8 in JSON format as follows:

Topic `+/ready`:
```
{
	"checkpoint" : {
		// ID required 
		"id" : "…",
		// Optional metadata
		"name" : "…",
		"description" : "…",
		"geo" : {
			"lat" : 0.000,
			"lng" : 0.000,
			"elevation" : 0.000
		},
	},
	"timestamp"  : 0000000
}
```
Readiness messages only require checkpoint identifier and timestamp (the Unix time of the device after synchronizing with a NTP server). 

Topic `+/checkpoint`:
```
{
	"checkpoint" : { 
		"id" : "…",			// Required
		"geo" : { "…" }		// (Optional) It can be included in case the checkpoint is on the move
	},
	"bibIdentifier" : "…",	// Either 'bib' or 'epc' are required
	"epcIdentifier" : "…",
	"timestamp"  : 0000000, 	// Required
}
```
For check-in messages, it is required the checkpoint identifier (some information may be added, such as coordinates in case the checkpoint is on the move), the unique identifier of the competitor (we can have several, such as bib number and RFID tag), and the timestamp of the check-in. 

## Implementation with Mosquitto and Paho

[Eclipse Mosquitto](https://mosquitto.org/) is an open source message broker that implements the MQTT protocol versions 3.1 and 3.1.1. This server is really stable and lightweight so it can be installed in any kind of computer, even on your Raspberry Pi.

Installation and configuration of the Mosquitto Broker is really easy (check [official page](https://mosquitto.org/download/) for instructions). For this pilot, I installed the Mosquitto Broker on a UP² Squared I received for this challenge –thanks, it's great!

I installed it from the Mosquitto Debian Repository with *apt* just in a few steps: 

After connecting via SSH with the UP² Squared.

```
wget http://repo.mosquitto.org/debian/mosquitto-repo.gpg.key
sudo apt-key add mosquitto-repo.gpg.key 
```

Repository available to apt:

```
cd /etc/apt/sources.list.d/
sudo wget http://repo.mosquitto.org/debian/mosquitto-wheezy.list
```

Update apt information and install Mosquitto

```
apt-get update
apt-get install mosquitto
```

As a summary of the configuration of this broker:

* Configuration file: `/etc/mosquitto/mosquitto.conf`
* Logs: `/var/log/mosquitto/mosquitto.log`

Mosquito service can be managed with this command: 

```
sudo service mosquitto [start|stop|restart]
```

The listener by default will open the `1883` port. Through the configuration file, we can set up the server. There is a sample file with all options listed and documented at `/usr/share/doc/mosquitto/examples/mosquitto.conf`.

There, we can configure all the security specifications of our broker (user/password files, SSL/TLS support, bridges, etc.). 

For this pilot we don't include security measures but communications should be private and secured in the production environment. 
 
In case we want to test the broker, we can also install the pub-sub clients anywhere.  

```
apt-get install mosquitto-clients
```

Opening several terminal sessions, we can simulate subscribers (`mosquitto_sub`) and publishers (`mosquitto_pub`) with just these options:
* -h (hostname)
* -t (topic)
* -m (message)

Do not forget to open that port on your firewall to make it available from outside your network.

### Paho 

*Checkpoints* are implemented using [Eclipse Paho](https://www.eclipse.org/paho/). Paho provides open-source client implementations of MQTT protocols for any platform. Paho implementations may be deployed on all checkpoint modules of ActivIoTy Timekeeping: Raspberry + Python; UP<sup>2</sup> Squared + Python/embedded C; Arduino + embedded C).

Paho is also the base for the implementation of the *Controller* (subscriber), coded in Node.js. 

[pubsub]: ./images/components/pubsub.png "ActivIoTy Timekeeping PubSub Process"

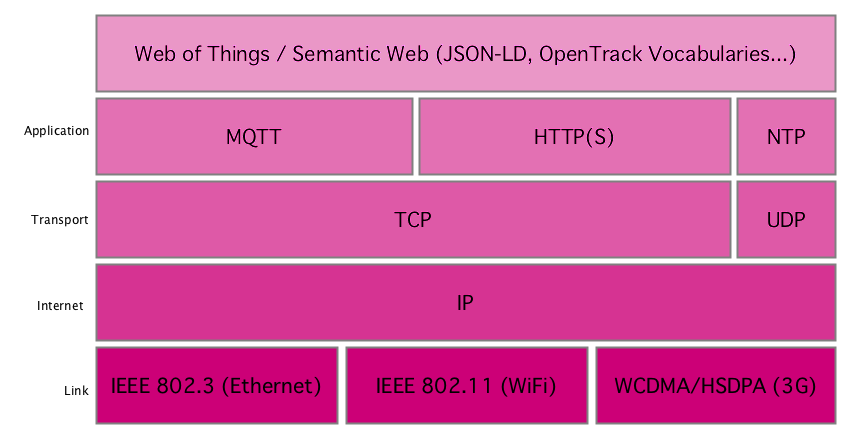
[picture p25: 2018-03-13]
docs/images/layer-design/protocol-layer2.png

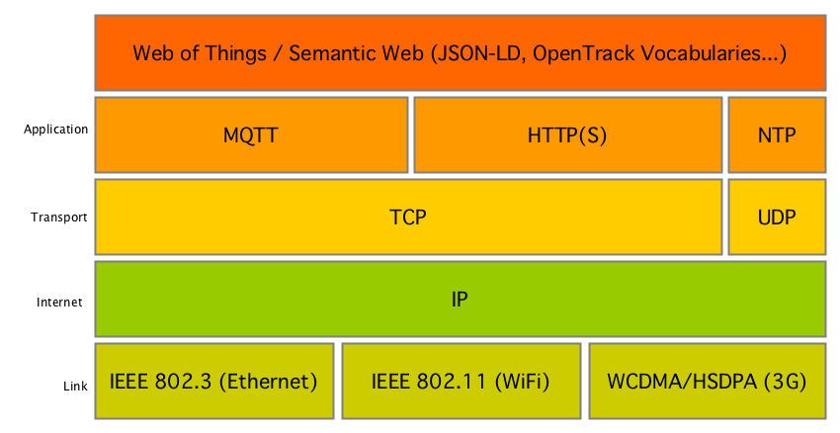
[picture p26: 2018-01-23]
docs/images/layer-design/protocol-layer.png

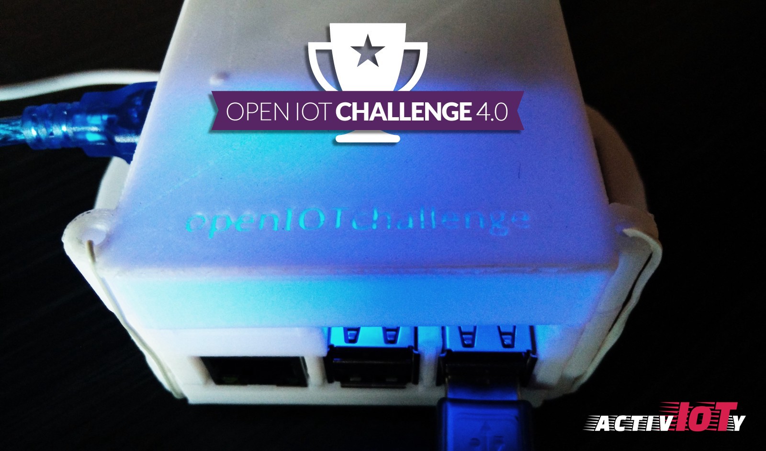
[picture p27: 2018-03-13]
docs/images/rfid_case_challenge.jpg

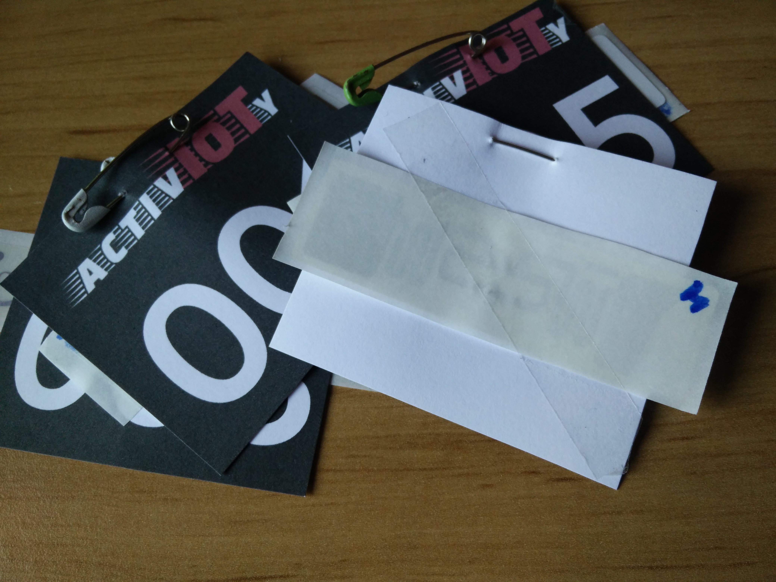
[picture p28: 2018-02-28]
docs/images/implementation/rfid_tags_3.jpg

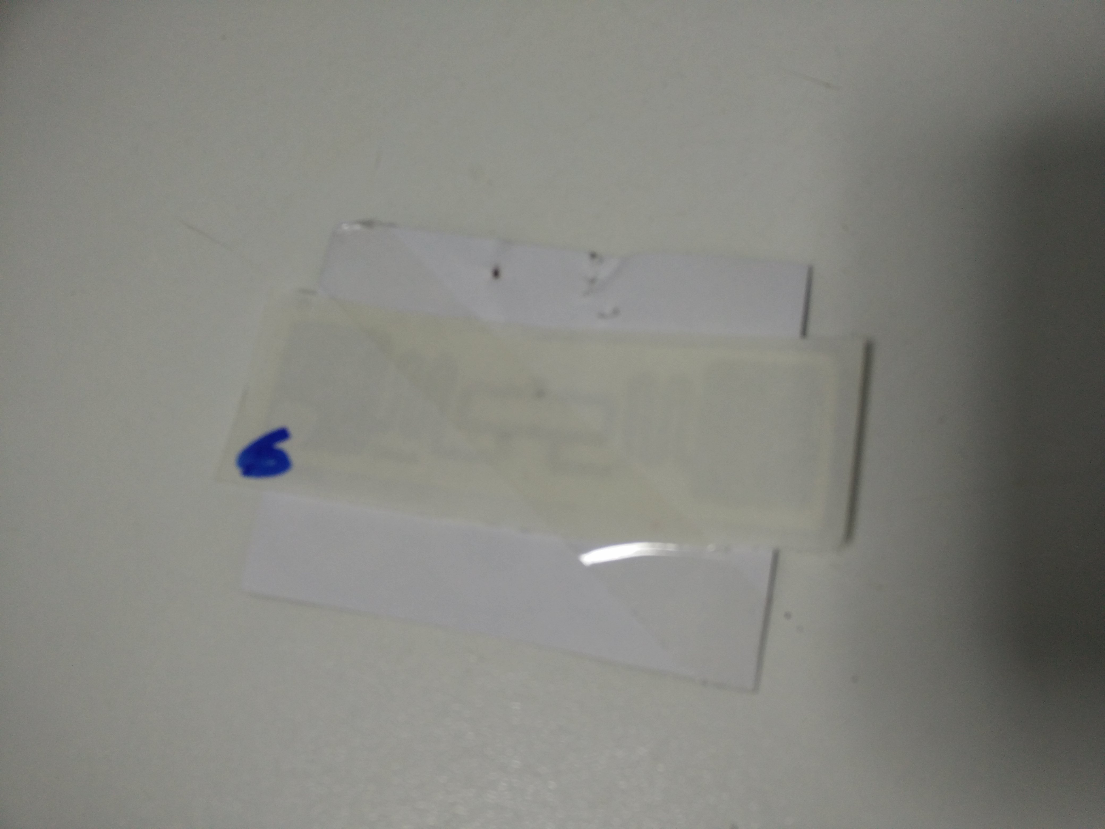
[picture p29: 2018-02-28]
docs/images/implementation/rfid_tags1.jpg

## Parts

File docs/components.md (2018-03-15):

# Components

components

## *Checkpoints* and *Controller*

These are the main pieces of ActivIoTy Timekeeping. The **Controller** is a server that manages and controls the timekeeping system. It stores basic information about each race such as `startDateTime` (timestamp with the official starting time) and the configuration of the `itinerary` of the running course. The itinerary is a sequence of one or more **Checkpoints** where runners must go to and check-in in order to complete the race.

Thus, *Checkpoints* are virtual gates located along the course of the race where runners must go through. Checkpoints register the competitor's ID and a timestamp that marks the official check time at that point of the race. **Checkpoints** must indicate the **Controller** that are in operation and they will send all the information to the **Controller**. 

The check process at *Checkpoints* may vary depending on the features of the device in use. For instance, some *Checkpoints* may read UHF RFID tags; others may be based on physical keyboards where marshals type the bib numbers when competitors go through the virtual gate. 

In terms of arquitecture, both *Controller* and *Checkpoint(s)* are **MQTT Clients**. These clients will be implemented using the specific [Eclipse Paho](https://www.eclipse.org/paho/) distribution, that provides solutions for all device platforms the project has. 

## MQTT Broker

Apart from these MQTT *pubsub* clients there is a **MQTT Broker** in charge of delivering messages. It is not repesented in the image to simplify the model. 

Eclipse [Mosquitto](https://mosquitto.org/) is the implementation selected for the MQTT Broker. This Open Source MQTT v3.1/v3.1.1 Broker will be installed on a reliable device with a strong internet connection.

## Personae

Three main roles will operate ActivIoTy Timekeeping:

* **Admin**: The person in charge of setting up the system (i.e., definition of checkpoints itinerary, assigning IDs to competitors, and others).
* **Official**: The person that will control the race, acting as starter of the race (e.g., setting `startDateTime`).
* **Competitors**: Runners/cyclists/… that take part in the competition. They are part of the checkpoint registration event.

## NTP Timing Accuracy

Synchronization of both *Checkpoints* and *Controller* is the cornerstone of the platform. Because of this, one first initialization tasks of every device is to set the 'official' time and date. This is done by using [**NTP** (Network Time Protocol)](http://www.ntp.org/ntpfaq/NTP-s-def.htm) external servers (e.g., [pool.ntp.org](http://pool.ntp.org) or [time.google.com](http://time.google.com)).   

## MQTT Reliability

Reliability is more important than efficiency in this project. Some checkpoints may have a poor internet connection and suffer interruptions, so ActivIoTy Timekeeping uses the MQTT protocol to guarantee the completeness of data. The system will implement **QoS 1 (at least once)**. Using QoS level 1, it is guaranteed that a message will be delivered at least once to the receiver. Messages can be delivered more than once but this will be taken into account and solved by the *Controller*.  

## HTTP Server

There is a public HTTP server that publish information about the system and enable the full configuration of ActivIoTy Timekeeping. This is the main interface either for public users and administrators. This server may deploy subsequent services built on top of ActivIoTy Timekeeping (e.g., social network integration, direct publication to media agencies, etc.).

Information will be published using Web Standards that guarantee interoperability.

[components]: ./images/components/checkpoints.png "Components in the ActivIoTy Timekeeping system"

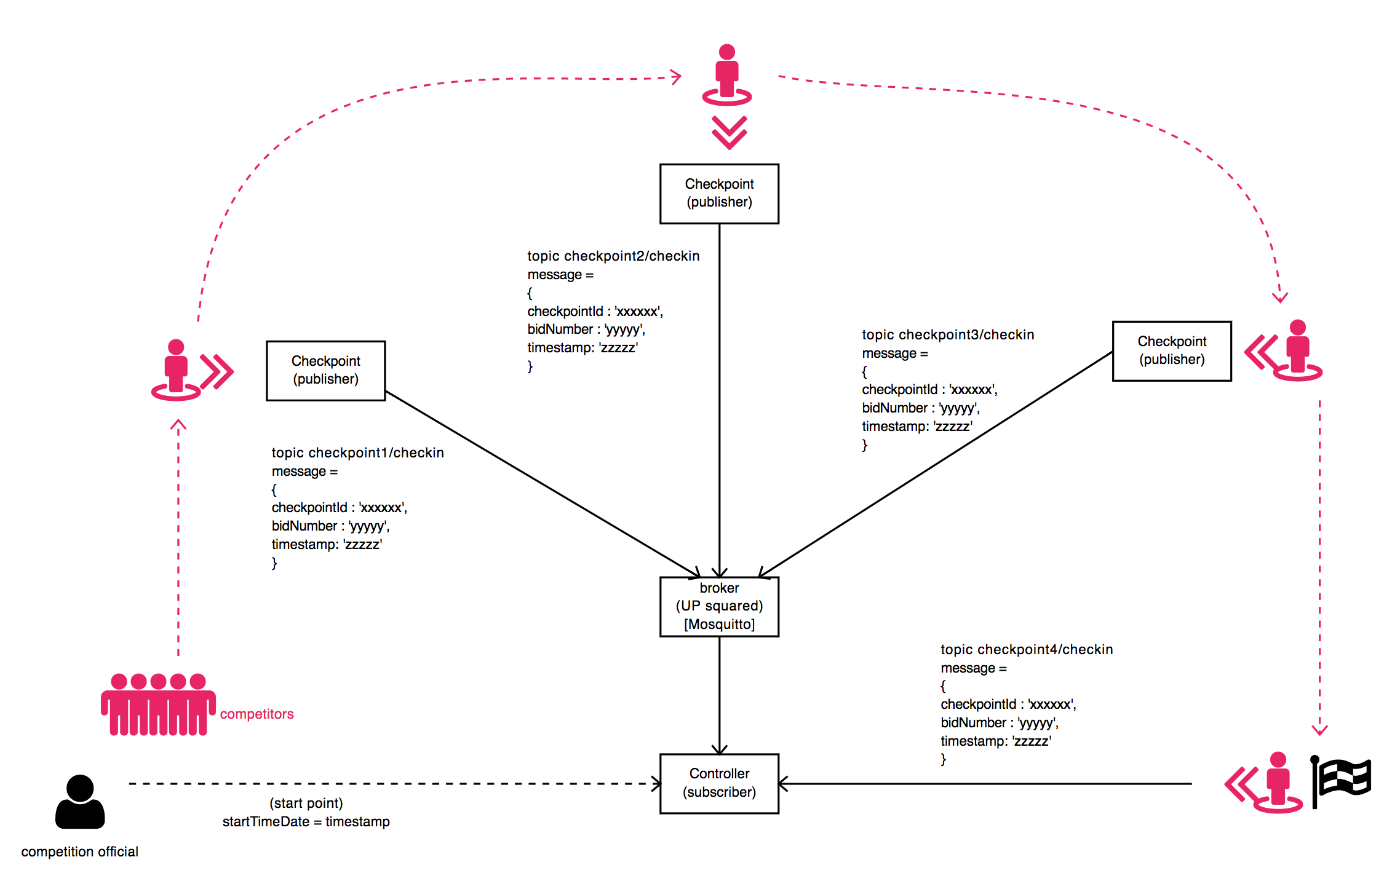
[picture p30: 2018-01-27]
docs/images/components/pubsub.png

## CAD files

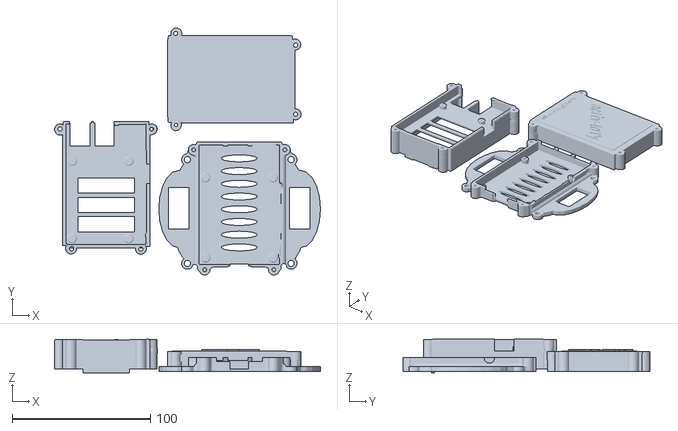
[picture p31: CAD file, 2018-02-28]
docs/checkpoints/rfid-reader-python/3D_model_RFID Reader + Antenna + RPi.stl
192.4 x 178.7 x 24.5

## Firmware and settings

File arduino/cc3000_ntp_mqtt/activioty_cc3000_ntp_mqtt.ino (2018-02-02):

/***************************************************
  This is an MQTT publish example for the Adafruit CC3000 Wifi Breakout & Shield
  
  This script is based on the PubSubClient with AdaFruit CC3000 library support by nathanchantrell 
  [https://github.com/nathanchantrell/pubsubclient].
 ****************************************************/

#include <Adafruit_CC3000.h>
#include <ccspi.h>
#include <SPI.h>
#include "cc3000_PubSubClient.h"

// Configuration of CC3000 Wifi Shield
// These are the interrupt and control pins
#define ADAFRUIT_CC3000_IRQ   3  // MUST be an interrupt pin!
// These can be any two pins
#define ADAFRUIT_CC3000_VBAT  5
#define ADAFRUIT_CC3000_CS    10

// Use hardware SPI for the remaining pins
// On an UNO, SCK = 13, MISO = 12, and MOSI = 11
Adafruit_CC3000 cc3000 = Adafruit_CC3000(ADAFRUIT_CC3000_CS, ADAFRUIT_CC3000_IRQ, ADAFRUIT_CC3000_VBAT, SPI_CLOCK_DIVIDER);

// Wifi Configuration SSID + Pasword + Security Method 
#define WLAN_SSID       "xxxxxxxxxxxx"
#define WLAN_PASS       "xxxxxxxxxxxx"
// Security can be WLAN_SEC_UNSEC, WLAN_SEC_WEP, WLAN_SEC_WPA or WLAN_SEC_WPA2
#define WLAN_SECURITY   WLAN_SEC_WPA2


Adafruit_CC3000_Client client;
     
// We're going to set our broker IP and union it to something we can use
union ArrayToIp {
  byte array[4];
  uint32_t ip;
};

// MQTT Broker Configuration
ArrayToIp MQTT_BROKER =         { 157, 0, 168, 192 };
#define MQTT_BROKER_PORT        1883
// User and Password for the broker connection
#define MQTT_USER               "user"
#define MQTT_PASS               "pass"
                                // ID is MAC|name
#define MQTT_CLIENTID           "001994372BB2|arduinowifi"
#define MQTT_TOPIC              "/activioty"


const unsigned long
  ntpConnectTimeout  = 25L * 1000L, // Max time to wait for server connection
  ntpResponseTimeout = 25L * 1000L; // Max time to wait for data from server
unsigned long
  initialTime  = 0L,      // Initial value retrieved from NTP server
  sketchOffset = 0L;      // Initial value in seconds when initialTime was set    

cc3000_PubSubClient mqttclient(MQTT_BROKER.ip, MQTT_BROKER_PORT , callback, client, cc3000);

void callback (char* topic, byte* payload, unsigned int length) {
}

String mqttMessage;

void connectToWifi(void) 
{
  displayDriverMode();
  
  Serial.println(F("\nInitialising the CC3000 ..."));
  if (!cc3000.begin()) {
    Serial.println(F("Unable to initialise the CC3000! Check your wiring?"));
    for(;;);
  }

  uint16_t firmware = checkFirmwareVersion();
  if ((firmware != 0x113) && (firmware != 0x118)) {
    Serial.println(F("Wrong CC3000 firmware version!"));
    for(;;);
  }
  
  displayMACAddress();
  
  Serial.println(F("\nDeleting old connection profiles"));
  if (!cc3000.deleteProfiles()) {
    Serial.println(F("Failed!"));
    while(1);
  }

  /* Attempt to connect to an access point */
  char *ssid = WLAN_SSID;             /* Max 32 chars */
  Serial.print(F("\nAttempting to connect to ")); Serial.println(ssid);
  
  /* NOTE: Secure connections are not available in 'Tiny' mode! */
  if (!cc3000.connectToAP(WLAN_SSID, WLAN_PASS, WLAN_SECURITY)) {
    Serial.println(F("Failed!"));
    while(1);
  }
   
  Serial.println(F("Connected!"));
  
  /* Wait for DHCP to complete */
  Serial.println(F("Request DHCP"));
  while (!cc3000.checkDHCP()) {
    delay(100); // ToDo: Insert a DHCP timeout!
  }

  /* Display the IP address DNS, Gateway, etc. */  
  while (!displayConnectionDetails()) {
    delay(1000);
  }
}

void connectToMQTTBroker(void) 
{
   // connect to the broker
   if (!client.connected()) {
     Serial.println(MQTT_BROKER.ip);
     client = cc3000.connectTCP(MQTT_BROKER.ip, 1883);
   }
   
   Serial.println(F("Connected TCP layer"));
   
   // did that last thing work? sweet, let's do something
   if(client.connected()) {
    if (mqttclient.connect(MQTT_CLIENTID, MQTT_USER, MQTT_PASS)) {
      Serial.println(F("Connected to MQTT broker"));
      char buffer[100];
      mqttMessage = String(MQTT_CLIENTID);
      mqttMessage += " is online!";
      mqttMessage.toCharArray(buffer, 100);
      mqttclient.publish(MQTT_TOPIC, buffer);
    }
   }
}

void setup(void)
{
  Serial.begin(115200);
  Serial.println(F("CC3000 + MQTT Publishing\n"));
  
  connectToWifi();
  setupTime();
  connectToMQTTBroker();

  // if analog input pin 0 is unconnected, random analog
  // noise will cause the call to randomSeed() to generate
  // different seed numbers each time the sketch runs.
  // randomSeed() will then shuffle the random function.  
  randomSeed(analogRead(0));
}

void loop(void) {
 
  // It will reconnect in case it was disconnected at some point
  if (!client.connected()) {
    client = cc3000.connectTCP(MQTT_BROKER.ip, 1883);
     
    if(client.connected()) {
      if (mqttclient.connect(MQTT_CLIENTID, MQTT_USER, MQTT_PASS)) {
        char buffer[100];
        mqttMessage = String(MQTT_CLIENTID);
        mqttMessage += " is online again!";
        mqttMessage.toCharArray(buffer, 100);
        mqttclient.publish(MQTT_TOPIC, buffer);
      }
    } 
  } else {
    // Publish the message
    String tagId = String(random(1, 10000));
    mqttMessage += tagId;
    unsigned long time = nowInUnixTime();
    mqttMessage = String("{\"id\":\"");
    mqttMessage += MQTT_CLIENTID;
    mqttMessage += "\", \"timestamp\": ";
    mqttMessage += time;
    mqttMessage += ", \"tagid\": \"";
    mqttMessage += String(tagId);
    mqttMessage += "\"}";
    char buffer[100];
    mqttMessage += "}}";
    mqttMessage.toCharArray(buffer, 100);
    Serial.println(buffer);
    mqttclient.publish("/activioty", buffer);
  }

  delay(5000);
}


/**************************************************************************/
/*!
    @brief  Displays the driver mode (tiny of normal), and the buffer
            size if tiny mode is not being used

    @note   The buffer size and driver mode are defined in cc3000_common.h
*/
/**************************************************************************/
void displayDriverMode(void)
{
  #ifdef CC3000_TINY_DRIVER
    Serial.println(F("CC3000 is configure in 'Tiny' mode"));
  #else
    Serial.print(F("RX Buffer : "));
    Serial.print(CC3000_RX_BUFFER_SIZE);
    Serial.println(F(" bytes"));
    Serial.print(F("TX Buffer : "));
    Serial.print(CC3000_TX_BUFFER_SIZE);
    Serial.println(F(" bytes"));
  #endif
}

/**************************************************************************/
/*!
    @brief  Tries to read the CC3000's internal firmware patch ID
*/
/**************************************************************************/
uint16_t checkFirmwareVersion(void)
{
  uint8_t major, minor;
  uint16_t version;
  
#ifndef CC3000_TINY_DRIVER  
  if(!cc3000.getFirmwareVersion(&major, &minor))
  {
    Serial.println(F("Unable to retrieve the firmware version!\r\n"));
    version = 0;
  }
  else
  {
    Serial.print(F("Firmware V. : "));
    Serial.print(major); Serial.print(F(".")); Serial.println(minor);
    version = major; version <<= 8; version |= minor;
  }
#endif
  return version;
}

/**************************************************************************/
/*!
    @brief  Tries to read the 6-byte MAC address of the CC3000 module
*/
/**************************************************************************/
void displayMACAddress(void)
{
  uint8_t macAddress[6];
  
  if(!cc3000.getMacAddress(macAddress))
  {
    Serial.println(F("Unable to retrieve MAC Address!\r\n"));
  }
  else
  {
    Serial.print(F("MAC Address : "));
    cc3000.printHex((byte*)&macAddress, 6);
  }
}


/**************************************************************************/
/*!
    @brief  Tries to read the IP address and other connection details
*/
/**************************************************************************/
bool displayConnectionDetails(void)
{
  uint32_t ipAddress, netmask, gateway, dhcpserv, dnsserv;
  
  if(!cc3000.getIPAddress(&ipAddress, &netmask, &gateway, &dhcpserv, &dnsserv))
  {
    Serial.println(F("Unable to retrieve the IP Address!\r\n"));
    return false;
  }
  else
  {
    Serial.print(F("\nIP Addr: ")); cc3000.printIPdotsRev(ipAddress);
    Serial.print(F("\nNetmask: ")); cc3000.printIPdotsRev(netmask);
    Serial.print(F("\nGateway: ")); cc3000.printIPdotsRev(gateway);
    Serial.print(F("\nDHCPsrv: ")); cc3000.printIPdotsRev(dhcpserv);
    Serial.print(F("\nDNSserv: ")); cc3000.printIPdotsRev(dnsserv);
    Serial.println();
    return true;
  }
}


/**************************************************************************/
/*!
    @brief  Configuration of the internal time of the system, based on a 
    NTP query. This should be called during the setup phase.
    Returns the Unix time in case of success; 0 if fails.
*/
/**************************************************************************/
unsigned long setupTime(void) {
  unsigned long t = 0L;
  
  do{
    t = getNTPTime();
  } while(!t);                        // Query time server
  initialTime = t;                    // Save time globally
  sketchOffset = millis()/1000;  // Substracts the current

  Serial.print(F("Current UNIX time: "));
  Serial.print(initialTime);
  Serial.println(F(" (seconds since 1/1/1970 UTC)"));
  Serial.print(F("Internal Arduino clock: "));
  Serial.print(sketchOffset);
  Serial.print(F("seconds from startup "));
  return t;
}

/**************************************************************************/
/*!
    @brief  Get a timestamp in Unix seconds, based on the initial NTP time 
    and the millis() of the Arduino.
*/
/**************************************************************************/
unsigned long nowInUnixTime(void) {
  unsigned long now = initialTime + (millis()/1000) - sketchOffset;
  return now;
}


/**************************************************************************/
/*!
    @brief  Minimalist time server query; adapted from Adafruit Gutenbird sketch,
    which in turn has roots in Arduino UdpNTPClient tutorial.
*/
/**************************************************************************/
unsigned long getNTPTime(void) {

  uint8_t       buf[48];
  unsigned long ip, startTime, t = 0L;

  Serial.print(F("Locating time server..."));

  // Hostname to IP lookup; use NTP pool (rotates through servers)
  if(cc3000.getHostByName("time.google.com", &ip)) {
    static const char PROGMEM
      timeReqA[] = { 227,  0,  6, 236 },
      timeReqB[] = {  49, 78, 49,  52 };

    Serial.println(F("\r\nAttempting connection..."));
    startTime = millis();
    do {
      client = cc3000.connectUDP(ip, 123);
    } while((!client.connected()) &&
            ((millis() - startTime) < ntpConnectTimeout));

    if(client.connected()) {
      Serial.print(F("connected!\r\nIssuing request..."));

      // Assemble and issue request packet
      memset(buf, 0, sizeof(buf));
      memcpy_P( buf    , timeReqA, sizeof(timeReqA));
      memcpy_P(&buf[12], timeReqB, sizeof(timeReqB));
      client.write(buf, sizeof(buf));

      Serial.print(F("\r\nAwaiting NTP response..."));
      memset(buf, 0, sizeof(buf));
      startTime = millis();
      while((!client.available()) &&
            ((millis() - startTime) < ntpResponseTimeout));
      if(client.available()) {
        Serial.println(F("Reading NTP Response"));
        client.read(buf, sizeof(buf));
        t = (((unsigned long)buf[40] << 24) |
             ((unsigned long)buf[41] << 16) |
             ((unsigned long)buf[42] <<  8) |
              (unsigned long)buf[43]) - 2208988800UL;
        Serial.print(F("OK NTP!\r\n"));
      }
      client.close();
    }
  }
  if(!t) Serial.println(F("error NTP"));
  return t;
}

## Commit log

2018-01-24 Library to communicate with IND903 device in Python
2018-01-28 Information about the IR+Arduino checkpoint
    [ir-arduino.fzz]
2018-01-30 CC3000 + NTP + MQTT for Arduino
2018-02-02 CC3000 + NTP + Arduino sketch
2018-02-28 3D Model of the Checkpoint case
    [3D_model_RFID Reader + Antenna + RPi.stl]
2018-03-10 Another example of USB keyboard + Raspberry Pi
